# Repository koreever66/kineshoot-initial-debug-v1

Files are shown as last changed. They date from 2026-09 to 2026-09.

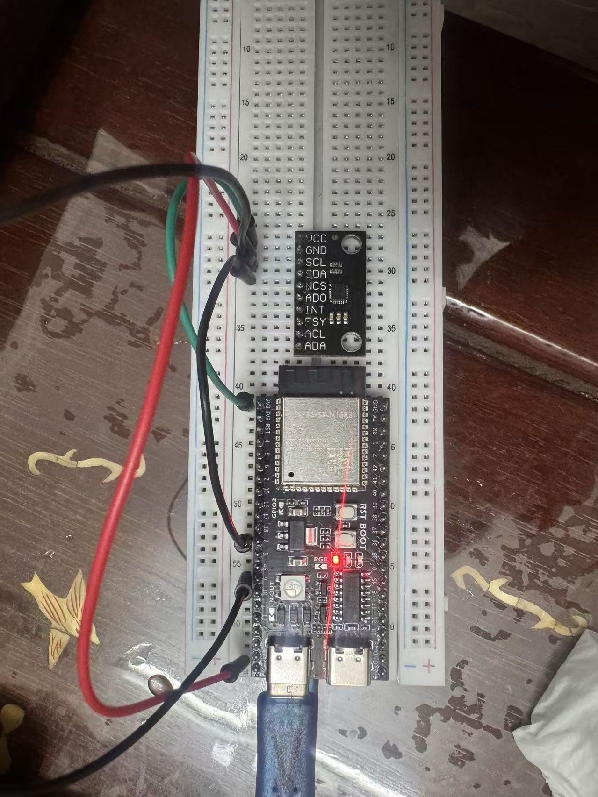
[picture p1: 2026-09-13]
photos/breadboard_rotated.jpg

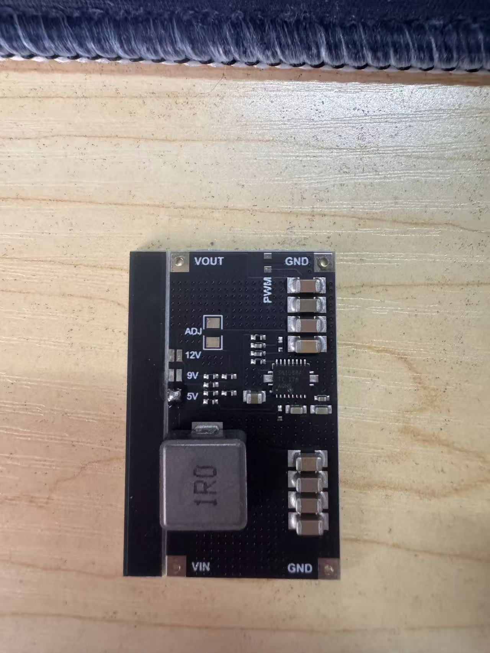
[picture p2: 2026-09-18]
photos/H2/2026-09-18_tps61088_front.jpg

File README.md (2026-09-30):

# 投篮发力链项目：初版硬件调试

本仓库只保存 ESP32-S3 与 ICM-20948 的硬件到货、焊接、接线、固件和第一轮数据采集内容。

不包含此前的项目计划书、商业计划、比赛报名资料和商品采购截图。

## 当前软件入口

- 软件仓库：`https://github.com/koreever66/kineshoot-initial-debug-v2`
- 软件分支：`codex/software-data`
- 软件提交：`ef92a97`（BLE 控制、iOS App、1080p60 与灯光预卷版本）
- 当前基线：`KB-2026-09-15-H1-F4-I1`

本硬件仓库中的 `legacy/` 只保留旧 v1 固件、工具和数据，不用于当前采集。

## 当前基线

```text
software_baseline_id = KB-2026-09-15-H1-F4-I1
software_repository  = koreever66/kineshoot-initial-debug-v2
software_branch      = codex/software-data
software_commit      = ef92a97
interface_revision   = I1
hardware_revision    = H2
```

当前硬件接口：

```text
VCC  -> 3V3
GND  -> GND
ICM SDI/SDA  -> GPIO8
ICM SCLK/SCL -> GPIO9
NCS  -> 3V3
AD0  -> GND
I2C address = 0x68
I2C clock   = 50kHz
WHO_AM_I    = 0xEA
```

详细说明见：

- `docs/hardware/SOFTWARE_BASELINE.md`
- `docs/hardware/H2_HANDOFF.md`
- `docs/hardware/H2_ASSEMBLY_RUNBOOK.md`
- `docs/hardware/SOFTWARE_SYNC_2026-09-19.md`
- `docs/hardware/BATTERY_BOOST_VALIDATION_2026-09-19.md`
- `docs/hardware/FIXATION_RUNBOOK_2026-09-20.md`
- `docs/hardware/WEARABLE_DIRECTION_CALIBRATION_2026-09-21.md`
- `docs/hardware/FIELD_CAPTURE_VALIDATION_2026-09-21.md`
- `docs/hardware/ESP32_REPLACEMENT_BLE_APP_2026-10-01.md`
- `docs/hardware/DUAL_NODE_PLAN_2026-09-20.md`
- `docs/hardware/MEASUREMENT_SHEET_NODE2_2026-09-20.md`
- `docs/hardware/design/node2_preassembly_v1.png`
- `cad/node2_case/README.md`
- `docs/hardware/design/node2_open_top_v1/`
- `docs/hardware/H2_BOM.csv`
- `docs/hardware/WEARABLE_DIMENSIONS.md`
- `docs/hardware/ORDER_RECEIPTS_2026-09-15.md`
- `docs/hardware/DAILY_DEBUG_SUMMARY_2026-09-16.md`
- `reference/software-baseline/`

## 当前硬件

- ESP32-S3-DevKitC-1，N16R8
- ICM-20948 九轴传感器模块
- 面包板和杜邦线
- USB 数据线
- 602535 500mAh 受保护锂电池 ×2
- TP4057-500mA 充电板 ×2
- TPS61088 固定 5V 升压模块 ×1
- SS-12E07G4 3A 开关和 SS12D07VG4 备用开关
- PH2.0 2P/4P 连接器、26AWG 红黑柔性线、热缩管
- 传感器盒、前臂软袋、EVA 泡棉、腕带和前臂绑带
- 电脑：Windows，Arduino IDE 2.3.10

## 目录

```text
legacy/firmware-v1/imu_plotter/     早期串口实时曲线固件
legacy/firmware-v1/imu_csv_logger/  早期 CSV 数据采集固件
legacy/tools-v1/                    早期串口采集和 CSV 绘图脚本
legacy/data-v1/                     早期原始 CSV 数据
legacy/plots-v1/                    早期 CSV 生成的曲线图
photos/                     焊接和面包板接线照片
DEBUG_NOTES.md              问题、解决思路和结果记录
docs/hardware/              H2 固定接口、BOM、装配和测试方案
reference/software-baseline/ 软件固定提交的只读参考文件
```

## 当前状态

- 面包板阶段已经完成 ESP32-S3 与 ICM-20948 通信验证。
- 腕部原 ESP32-S3 在采集第 6 组时出现过热和 BOOT 区域损坏，现已替换为原 Node 2 备用的 ESP32-S3 DevKitC-1 N16R8；接线保持不变。
- 历史阶段出现过 `0x68`、`0x69`、`0x0C` 和 `100kHz`，这些不再作为当前实现目标。
- 当前接口固定为 `0x68`、`50kHz`、`WHO_AM_I=0xEA`。
- 当前软件基线为 F4，使用 10 秒 RAM 记录、LittleFS 批量写入、BOOT 备用触发和 BLE 控制触发。
- 已加入 iPhone 配套 App：`KineShootRemote 1.5.1 (8)`，支持 1080p60、前置/后置切换、缩放、1 秒蓝灯预卷和 14 秒录像。
- 绿灯表示 CSV 与 telemetry 写入完成，不等于球员动作结束；已验证绿灯和 telemetry 可用于对齐视频与 IMU。
- H2 物料已于 2026-09-18 到齐；首版主电源路径为 `电池 -> TP4057 -> SS-12E07G4 3A 开关 -> TPS61088 固定 5V -> ESP32 5V`，不使用 P-MOS。
- H2 已进入实体装配和电气验证阶段；照片、万用表和静止/动态测试尚未完成。

## 下一步

1. 按 `docs/hardware/H2_ASSEMBLY_RUNBOOK.md` 先做电池、TP4057 的断电通断检查和独立充电测试。
2. 按 `docs/hardware/H2_HANDOFF.md` 焊接 PH2.0 和柔性线束；固定 NCS=3V3、AD0=GND。
3. 先只用 USB 验证 `0x68` 和 `WHO_AM_I=0xEA`，再接入升压电源链。
4. 完成腕部固定、前臂固定和应力释放。
5. 完成 10 秒静止测试和小幅动态测试。
6. 对替换后的 ESP32 做电池供电 BLE 连续采集，检查温升、复位、丢样和结构固定。
7. 提交 H2 照片、测试结果和已知风险。

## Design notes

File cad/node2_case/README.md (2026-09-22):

# Node 2 Upper-Arm Open Case

Parametric JSCAD model for the second-node upper-arm enclosure.

```text
revision: N2-CASE-OPEN-V1.2
body outer size: 125 x 75 x 32 mm
internal nominal: 120 x 70 x 23.5 mm
top: open perimeter fence, no lid
arm circumference input: 300 mm relaxed / 317 mm flexed
bottom cradle sagitta: 6 mm
strap interface: two external stations, direct 50 mm strap
```

## Commands

```bash
npm install
npm run build
npm run render
npm run serve
```

- `build`: exports STL, 3MF, and the layout manifest into `out/`.
- `render`: uses local Chrome or Edge through Playwright Core to create isometric, top, and side PNG previews.
- `serve`: starts the interactive Three.js viewer.

The shell model excludes electronic modules. Module blocks in the viewer and manifest are mechanical placeholders only.

Measured inputs currently applied:

```text
lateral upper-arm width: 100 mm
ESP32 envelope: 63.6 x 27.94 x 12 mm
TPS61088 maximum height: 11 mm
battery safe envelope: 43 x 30 x 15 mm
dual Type-C opening: one 32 x 7 mm rectangular slot
strap natural / comfortable length: 500 mm / 680-700 mm
```

The ICM maximum bent height measured by the user is 32 mm. The current model assumes the ICM is laid sideways and its 4P cable is routed flat. Verify the installed height after that routing before the final print; if it exceeds 23.5 mm above the deck, raise the fence parameter.

Revision V1.2 shortens the ICM partition to the distal/front pocket so it no
longer crosses the TPS61088 footprint. The build also checks every module
against the partition, not only against the outer walls.

## Generated Files

```text
out/node2_open_top_v1.stl
out/node2_open_top_v1.3mf
out/node2_open_top_v1_manifest.json
out/node2_open_top_v1_preview_iso.png
out/node2_open_top_v1_preview_top.png
out/node2_open_top_v1_preview_side.png
```

The current model keeps the fixed electrical interface unchanged:

```text
ICM VCC       <- ESP32 3V3
ICM GND       <- ESP32 GND
ICM SDI/SDA   <- GPIO8
ICM SCLK/SCL  <- GPIO9
ICM NCS       -> 3V3
ICM AD0       -> GND
address       = 0x68
clock         = 50kHz
WHO_AM_I      = 0xEA
```

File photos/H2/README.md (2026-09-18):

# H2 Photo Manifest

Put H2 assembly and verification photos in this directory.

Arrival and pre-check evidence captured on 2026-09-18:

- `2026-09-18_tps61088_front.jpg`: actual TPS61088 front side with VIN/VOUT/GND, 5V/9V/12V/ADJ pads and PWM pad.
- `2026-09-18_tps61088_back.jpg`: actual TPS61088 back side and dimensions marking.
- `2026-09-18_tp4057_500ma.jpg`: actual TP4057-500mA board and four BAT through-holes.

Required photos:

1. ESP32 and ICM wiring overview.
2. Both ends of the PH2.0 4P connector.
3. Close-up of ICM NCS tied to 3V3 and AD0 tied to GND.
4. Battery-to-TP4057 solder joints.
5. Switch and boost module placement.
6. Wrist-mounted sensor unit, front and back.
7. Forearm battery and main unit pouch.
8. Full wearable placement.
9. Strain relief close-up.
10. Multimeter continuity or voltage checks.

Do not upload screenshots containing personal information, order pages, names, phone numbers, or addresses.

These arrival photos are not verification evidence for soldering, charging, boost output, mechanical fit, or motion testing.

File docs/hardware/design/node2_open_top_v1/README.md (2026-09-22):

# Node 2 Open-Top Preview v1

Previews generated from `cad/node2_case`.

```text
preview_iso.png  isometric view
preview_top.png  top view with module placeholders
preview_side.png side view showing the open fence and shallow cradle
```

Printable model files:

```text
cad/node2_case/out/node2_open_top_v1.stl
cad/node2_case/out/node2_open_top_v1.3mf
```

Design summary:

```text
body outer size: 125 x 75 x 32 mm
internal nominal: 120 x 70 x 23.5 mm
top: open
strap stations: two, direct 50 mm strap hooks
arm circumference: 300 mm relaxed / 317 mm flexed
ICM partition: distal/front pocket only; checked against module footprints
```

This is a prototype mechanical enclosure. It does not modify the ICM, ESP32, power path, firmware, or software protocol.

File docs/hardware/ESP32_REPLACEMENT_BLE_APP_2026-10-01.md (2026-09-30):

# ESP32 Replacement, BLE Trigger, and Mobile App - 2026-10-01

## Replacement Event

The previous wrist-node ESP32-S3 failed while triggering capture 6. The operator reported a burning smell. The original red power LED and GPIO48 RGB LED no longer illuminated, and visible damage was found around the BOOT-key area. Power was removed immediately and the board was retired.

The spare ESP32-S3 DevKitC-1 N16R8 originally reserved for Node 2 was installed in the wrist-node position.

The electrical interface did not change:

```text
ICM VCC       -> ESP32 3V3
ICM GND       -> ESP32 GND
ICM SDI/SDA   -> GPIO8
ICM SCLK/SCL  -> GPIO9
ICM NCS       -> 3V3
ICM AD0       -> GND
BOOT trigger  -> GPIO0 to GND
RGB status    -> GPIO48
I2C address   -> 0x68
I2C clock     -> 50 kHz
WHO_AM_I      -> 0xEA
```

Initial bring-up was performed with USB only. The battery, TP4057, power switch, and TPS61088 were disconnected during flashing and first validation.

## BLE and App Integration

Firmware now advertises only the custom BLE control service:

```text
Name: KineShoot-Cam
Service UUID: 6b1d0001-9a3f-4d2a-8f6f-6b1d00000001
Characteristic UUID: 6b1d0002-9a3f-4d2a-8f6f-6b1d00000002
Command 0x01: start capture
```

The iPhone app starts video recording, waits one second to record the blue-light pre-roll, then writes `0x01` to the ESP32. The ESP32 performs the same capture routine used by the BOOT fallback.

Expected serial handshake:

```text
BLE_CONTROL_READY,name=KineShoot-Cam,...
BLE_CONNECTED
BLE_COMMAND,capture
CAPTURE_START,file=/capture_001.csv,seconds=10
CAPTURE_DONE,...
```

The current app build is `KineShootRemote 1.5.1 (8)`, with 1080p60, front/rear switching, zoom, a 1-second blue pre-roll, and a 14-second recording window.

## Verification on the Replaced Board

The replacement board completed:

- USB flashing and serial initialization
- ICM-20948 initialization at `0x68`
- repeated 10-second captures
- LittleFS CSV and telemetry writes
- BOOT-triggered capture
- BLE-triggered capture from the iPhone app
- RGB state changes visible in 60 fps video

One verified alignment session is:

```text
session_20261001_034814/capture_001.csv
2268 rows, 9.9904 s, 226.92 Hz
```

The corresponding 15.61-second 1080p60 video shows the green write-complete LED at approximately `12.526 s`. Telemetry reports `11.535 s` from capture start to write completion, giving an estimated IMU start at approximately `0.991 s` in the video, consistent with the configured 1-second blue pre-roll.

## Metadata Provenance Correction

The software side corrected exported metadata after this hardware review. Software commit `6f6e7fc` now records the replacement-board baseline as `H2`, adds a dedicated BLE/App export wrapper using `trigger_source = ble_command`, and preserves `boot_button` only for physical BOOT-triggered exports. The known `032715/capture_011-013` and `034814/capture_001` metadata were corrected without changing any CSV IMU values.

## Hardware Notes and Next Checks

- Green indicates that the CSV and telemetry write completed; it is not the physical end of the player's motion.
- Keep the camera aimed and focused on the device before pressing Start so the blue-to-red transition is recorded.
- Do not connect USB and the battery-boost output at the same time.
- Inspect the replacement board area after repeated captures for heating, connector strain, or intermittent resets.
- Secure the replacement board and strain-relieve the I2C/power wiring inside the enclosure.
- Run a battery-powered BLE capture series and compare sample continuity, reset count, and RGB behavior to the USB-powered baseline.
- Record the next enclosure revision or fastening change if the replacement board dimensions alter the current wrist-node fit.

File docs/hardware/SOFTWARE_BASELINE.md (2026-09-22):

# Software Baseline Reference

This file records the software baseline consumed by the hardware repository. The software repository remains the source of truth.

```text
software_baseline_id = KB-2026-09-15-H1-F4-I1
software_repository  = koreever66/kineshoot-initial-debug-v2
software_branch      = codex/software-data
software_commit      = ab44f2a
interface_revision   = I1
hardware_revision    = H2
```

## Read-Only Copies

The following files were copied from the fixed software commit into `reference/software-baseline/`:

| File | Source path | Git blob SHA |
|---|---|---|
| `CANONICAL_BASELINE.md` | `docs/CANONICAL_BASELINE.md` | `717afcd5a1f7dec0601232ad5305f42f7df4c3bd` |
| `INTERFACE.md` | `docs/INTERFACE.md` | `23475d58d4e2ef8b0a49b8c9174069124ae8cff5` |
| `project.json` | `project.json` | `4e9d042032dbe7b47f5d5ae87cf21e37db2b0cb8` |

These copies are read-only references. Hardware changes must not modify them.

## Fixed Interface

```text
ESP32-S3 GPIO8  <-> ICM-20948 SDI / SDA
ESP32-S3 GPIO9  <-> ICM-20948 SCLK / SCL
ESP32-S3 3V3    <-> ICM-20948 VCC
ESP32-S3 GND    <-> ICM-20948 GND
ESP32-S3 3V3    <-> ICM-20948 NCS
ESP32-S3 GND    <-> ICM-20948 AD0

I2C address: 0x68
I2C clock:   50 kHz
WHO_AM_I:    0xEA
```

## Prohibited

- Do not use `0x69` or `0x0C` as the long-term primary address.
- Do not leave `AD0` or `NCS` floating.
- Do not switch or bypass the 3.3V power path.
- Do not modify firmware, tools, data formats, record duration, triggers, or software protocol.
- Do not modify the software repository.

## F4 Runtime Contract

```text
firmware directory: firmware/imu_flash_logger_v4/
record duration:    15 seconds
buffering:          RAM during capture, batched LittleFS write after capture
sample rate:        nominal about 220-225 Hz
observed F4:        approximately 226.9 Hz in current exports
hardware acceptance 210-240 Hz or median interval 4.0-4.8 ms
maximum interval:   <=10 ms
accelerometer:      +/-16g
gyroscope:          +/-2000dps
trigger:            short press BOOT
USB CDC On Boot:    Enabled
status LED:         WS2812B RGB on GPIO48
LED colors:         blue=idle/running, red=capture, green=LittleFS write complete
power switch check: after changing source, proceed only when blue is on; if not, press RST once
export layout:      timestamped session directories
CSV fields:         timestamp_us, ax_mg, ay_mg, az_mg,
                    gx_dps, gy_dps, gz_dps, temp_c
metadata fields:    power_source, trigger_source, motion_speed
zero-sample guard:  reject 0-row capture files since software commit 9beb75a
field captures:     approximately 3403-3404 rows in the 2026-09-21 session
```

## Current Software Test Power Boundary

当前软件对话的测试供电仍然属于 H1：

```text
电脑 USB -> ESP32
或
充电宝 5V -> ESP32
```

因此当前软件测试不经过：

```text
电池
TP4057
3A 开关
TPS61088
```

软件接口只依赖：

- ESP32 5V 输入保持稳定。
- BOOT/GPIO0 和 RST 行为。
- GPIO48 RGB 状态反馈。
- USB CDC On Boot、采样、记录和导出协议。

H2 首版采用的直接 3A 开关属于硬件电源实现，不改变软件接口。P-MOS 只保留为实测不合格时的硬件回退方案。现阶段软件端使用电脑 USB 或充电宝测试时，不需要等待 H2 电源链完成。

进入 H2 整机测试后必须遵守：

- 电脑 USB 和电池输出不能同时连接。
- TP4057 充电时关闭负载。
- USB 烧录或导出时断开电池输出。
- ESP32 5V 输入必须来自单一电源，避免双 5V 倒灌。

Hardware owns only the physical implementation, power, connectors, mounting, and verification.

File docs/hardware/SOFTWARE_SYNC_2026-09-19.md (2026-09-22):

# Software-to-Hardware Sync 2026-09-19

软件端报告：`KineShoot_硬件联调测试报告_2026-09-19.docx`

固定基线：

```text
hardware_revision = H2
software_revision = F4
interface_revision = I1
software_commit = ab44f2a
ICM-20948 I2C = 0x68
I2C clock = 50kHz
WHO_AM_I = 0xEA
```

## 1. 已知通过项

- USB 供电下，START 和 BOOT 两次静止采集均通过。
- 两次 USB 数据均约 2269 到 2270 行，采样率约 226.9Hz，最大间隔小于 6.32ms。
- I2C 固定地址诊断持续返回 `tx=0, rx=1, who=0xEA`。
- 重新上传 F4 后，充电宝模式两次桌面静止采集恢复有效，均约 2270 行。
- 恢复后的两次数据无采样缺口、无饱和，重力模长约 997 到 999mg。
- 软件端 action-chain 会话已包含 6 次有效采集，并已加入 0 行空采集文件拒绝逻辑。
- 电池供电链路完成 5 次冷启动；随后 3 次静止和 2 次小幅举臂采集已由软件端验收通过。

## 2. 当前开放问题

### P0：切换供电后出现空表头采集

第一次从 USB 切到充电宝后，连续三次采集都只有 64 字节 CSV 表头，数据行为 0。重新检查连接并重刷 F4 后恢复，因此当前证据指向连接稳定性或供电切换过程，而不是采样算法。

当前状态：重新检查连接并重刷 F4 后已恢复；电池供电下 3 次静止加 2 次小幅举臂采集已通过软件端验收。

### P0：四线连接器、NCS、AD0 的机械稳定性

需要确认轻拨线束时：

- SDA/SCL 不中断。
- 地址始终保持 `0x68`；不出现 `0x0C`。
- `NCS` 与 `VCC` 保持导通。
- `AD0` 与 `GND` 保持导通。

### P1：ICM 端供电稳定

需要实测：

- ICM `VCC` 对 `GND` 约 3.3V。
- 充电宝接入、线束轻拨和静止记录期间没有明显跌落。
- `GND` 共地稳定。

### P1：从充电宝切回 USB 的冷启动时序

软件端观察到从充电宝切回 USB 后，连续三次按 RST 蓝灯未亮，第四次恢复。需要统计五次冷启动，区分 USB 枚举延迟、复位时序和 IMU 初始化重试。

当前状态：电池供电路径已完成 5 次冷启动，5/5 蓝灯恢复，无额外 RST、无反复复位、无保护板跳闸；USB 枚举延迟的历史现象继续保留为观察项。

## 3. 硬件端复测顺序

### 测试 A：I2C 静态稳定性

1. 只用电脑 USB 给 ESP32 供电。
2. 运行 I2C 扫描。
3. 轻拨四根 PH2.0 线束。
4. 轻拨 ICM 端 `NCS` 和 `AD0` 跳线。
5. 观察 2 到 3 分钟。

通过标准：

- [ ] 地址保持 `0x68`。
- [ ] `WHO_AM_I=0xEA` 稳定。
- [ ] 不出现 `0x0C`。
- [ ] 无通信中断。

### 测试 B：端点和供电测量

断电通断检查：

- [ ] `NCS` 对 `VCC` 导通。
- [ ] `AD0` 对 `GND` 导通。
- [ ] `VCC` 对 `GND` 不导通。
- [ ] SDA 对 GND 不导通。
- [ ] SCL 对 GND 不导通。

上电电压检查：

- [ ] ICM `VCC` 约 3.3V。
- [ ] ICM `GND` 与 ESP32 `GND` 共地。
- [ ] 轻拨线束后电压仍稳定。

### 测试 C：USB 静止采集

- [ ] 10 秒静止 BOOT 采集约 2269 行。
- [ ] `write_failed=0`。
- [ ] 无 ERR、无 reset。
- [ ] 最大间隔小于 10ms。

### 测试 D：充电宝静止采集

- [ ] 切换前先关闭或断开负载。
- [ ] 充电宝 5V 接入后等待 10 秒。
- [ ] 只做一次站立静止 10 秒采集。
- [ ] 约 2269 行，不能是 64 字节空表头。
- [ ] 轻拨线束时数据不中断。

### 测试 E：五次冷启动记录

每次按以下顺序执行：

```text
1. 拔掉 USB。
2. 等待 10 秒。
3. 重新插入 USB。
4. 等待 5 秒。
5. 只按一次 RST。
6. 最多等待 10 秒。
```

每次记录：

```text
第几次：
USB 插入后 COM5 出现时间：
按 RST 前灯色：
按 RST 后灯色：
串口首行：
IMU_INIT 状态：
是否一次恢复：
失败时是否有红灯：
失败时是否有 COM5：
```

通过标准：

- [ ] 连续五次冷启动都恢复。
- [ ] 或者明确记录失败模式，并证明失败原因不是接触不良。

## 4. 动态测试门槛

满足以下条件后，才继续举臂、蹲起和投篮动态测试：

- [x] 充电宝模式和电池模式下均完成有效静态采集并通过软件端验收。
- [ ] 最大间隔小于 10ms，20ms 以上缺口为 0。
- [ ] `write_failed`、饱和和复位均为 0。
- [x] 五次电池冷启动达到五次成功。
- [ ] 轻拉线束和切换供电时 ICM 数据通路不失效。

## 5. 责任边界

软件端负责：

- F4 固件零样本保护，当前已在软件提交 `9beb75a` 后实现。
- CSV 和元数据校验。
- 串口日志与采样算法分析。

硬件端负责：

- 四线连接器接触稳定性。
- NCS/AD0 固定电平的机械与电气可靠性。
- ICM 3V3/GND 供电稳定。
- 充电宝到 USB 的切换时序和冷启动记录。
- 线束应力释放和插头锁扣状态。

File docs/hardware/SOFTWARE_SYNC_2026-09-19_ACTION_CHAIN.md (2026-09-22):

# Software Sync - 2026-09-19 Action-Chain Validation

Software branch: `codex/software-data`

Software commit at action-chain validation: `1ec5968`

Latest validated software commit: `ab44f2a`

Last pushed software remote head at review time: `276b312`

## Purpose

Synchronize the hardware repository with the latest software-side validation
results before strap fixation and component embedding.

## Latest Validated Setup

```text
ESP32-S3
ICM-20948 at 0x68 / WHO_AM_I 0xEA
ICM VCC <- ESP32 3V3
ICM GND <- ESP32 GND
ICM SDI/SDA <- GPIO8
ICM SCLK/SCL <- GPIO9
ICM NCS -> 3V3
ICM AD0 -> GND
5 V power bank
BOOT-button capture trigger
```

The latest action-chain session contains six valid captures:

```text
static x2
slow arm raise x1
one simulated shot x1
two simulated shots x1
two squats x1
```

Each file has approximately 2269 rows, approximately 226.9 Hz sample rate, no
gaps of 20 ms or more, and no acceleration or gyroscope saturation.

## Hardware-Side Mechanical Requirements

- Preserve the current soldered four-wire connection.
- Add strain relief before the cable enters the ESP32 or ICM.
- Keep the sensor module mechanically isolated from the power bank.
- Secure the power bank so its cable cannot pull the ESP32 connector.
- Keep USB-C, BOOT, and RGB LED accessible.
- Do not coat solder joints directly with hot glue.
- Mark sensor orientation on the strap or enclosure.
- After assembly, repeat NCS-to-3V3, AD0-to-GND, and VCC-to-GND checks.

## Acceptance After Fixation

Before court shooting, repeat:

```text
3 static captures
2 arm-raise captures
```

All five captures must pass sample count, gap, saturation, and file-size checks.
If any capture fails, inspect the cable path before proceeding to dynamic
shooting.

## Battery and Boost Integration Sequence

The current power bank remains the validated capture baseline. Do not replace
it with the battery until the following sequence passes.

Target main path:

```text
3.7 V protected battery
-> TP4057 charge module BAT+ / BAT-
-> SS-12E07G4 3 A main switch on battery positive
-> TPS61088 fixed 5 V boost input
-> TPS61088 5 V output to ESP32 5V and GND
```

`SS12D07VG4` must not carry the main boost input current. It is only allowed in
the low-current P-MOSFET fallback control path.

Validation order:

1. Measure battery polarity and open-circuit voltage before connection.
   Expected approximately 3.0-4.2 V.
2. Connect only the battery to TP4057. Do not connect ESP32 or TPS61088 yet.
3. Charge through TP4057 and verify charging current is approximately 500 mA
   and final battery voltage is approximately 4.2 V.
4. Verify the TP4057 BAT+ / BAT- output polarity and voltage.
5. Add the SS-12E07G4 switch in the battery-positive main path.
6. Connect the switched battery output to TPS61088 input.
7. Verify TPS61088 no-load output is 5.00 V before connecting ESP32.
8. Apply a short 0.5-1 A load test. Output should remain at or above about
   4.85 V and the switch temperature should remain acceptable.
9. Connect TPS61088 5 V output only to ESP32 5V and GND. Never connect boost
   output to ESP32 3V3 or ICM VCC.
10. Confirm ESP32 boot has no brownout and ICM VCC remains approximately 3.3 V.
11. Run three static captures and two arm-raise captures on battery power.
12. Keep the power bank available as fallback until all five captures pass.

TP4057 does not provide load sharing. The ESP32 load must be switched off while
charging. Never connect USB 5 V and battery-boost 5 V to the ESP32 at the same
time.

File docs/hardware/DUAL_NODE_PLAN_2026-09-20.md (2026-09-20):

# Dual-Node Hardware Plan - 2026-09-20

Status: hardware proposal for the second node. Software protocol and time-sync method remain owned by the software conversation.

## 1. Target Architecture

Keep the two nodes electrically independent:

```text
Node 1: forearm
  battery B1 -> TP4057 -> switch -> TPS61088 5V -> ESP32 #1
  ICM #1 -> 4P cable -> ESP32 #1

Node 2: upper arm
  battery B2 -> TP4057 -> switch -> TPS61088 5V -> ESP32 #2
  ICM #2 -> 4P cable -> ESP32 #2
```

Do not connect the two nodes through a shared battery or shared 5V rail for the first revision.

2026-09-20 decision: Node 2 will use the second protected battery B2. The two nodes will not share a battery, 5V rail, or ground in the first revision. No inter-node signal wire will be installed until the software conversation defines the synchronization method.

## 2. Additional Hardware Required

Required:

- one ESP32-S3-N16R8 board
- one ICM-20948 module
- one TP4057-500mA charging module
- one fixed-5V TPS61088 boost module
- one 26AWG red and black silicone wire set
- one USB-C data cable for programming the second board
- two 5cm upper-arm elastic straps or equivalent reusable arm bands

Already available or reusable:

- battery B2, because two protected 602535 500mAh batteries were purchased
- spare SS-12E07G4 3A switch from the multi-pack
- PH2.0 4P connectors for the second ICM harness
- PH2.0 2P connectors for battery B2
- heat shrink, EVA foam, Velcro, labels, and spare flexible wire

Do not add a second battery-protection board in series unless the battery does not already contain one. The purchased 602535 cells already include protection boards.

## 3. Upper-Arm Placement

Proposed location:

```text
lateral upper arm
center approximately 10cm proximal to the elbow
long axis parallel to the humerus
```

Mechanical requirements:

- keep the case away from the elbow crease and shoulder
- use the distal end of the case for the ICM sensor
- use the proximal/upper end for the battery to move mass toward the shoulder
- keep the battery from pressing on the ICM compartment
- use EVA or a TPU liner on the skin-facing surface
- use two arm bands to prevent rotation and sliding
- mark node ID `N2` and an orientation arrow on the case

Keep the same fixed interface:

```text
ICM VCC       <- ESP32 3V3
ICM GND       <- ESP32 GND
ICM SDI/SDA   <- GPIO8
ICM SCLK/SCL  <- GPIO9
ICM NCS       -> 3V3
ICM AD0       -> GND
I2C address   = 0x68
I2C clock     = 50kHz
WHO_AM_I      = 0xEA
```

## 4. 3D-Printed Enclosure

Use a two-piece clamshell or removable-lid shell.

Recommended material:

```text
PETG, ASA, PA12, or another durable non-conductive material
```

Recommended structure:

- curved skin-facing surface matching the upper-arm radius
- 2.5 to 3mm wall thickness
- M2.5 heat-set inserts instead of screwing directly into printed plastic
- separate internal sensor compartment at the distal/elbow end
- main electronics compartment for ESP32, TPS61088, TP4057, and switch
- battery pocket separated from the boost module by foam
- cable channels with integrated strain-relief posts
- removable or transparent RGB window
- BOOT and RST access holes or a removable service window
- USB-C access aligned with the ESP32 COM port
- switch access without opening the lid

Do not place the battery or metal parts directly over the ESP32 antenna area. Keep the antenna at a plastic-only edge of the enclosure.

## 5. Sensor Isolation Inside the Shell

For the upper-arm node, place the ICM in a small internal pocket rather than directly bolting it to the main electronics plate.

- add 1 to 2mm EVA or TPU between ICM and shell
- anchor the 4P cable to the pocket before it reaches ICM solder joints
- leave a 1 to 2cm service loop
- keep battery and boost wiring away from the ICM cable
- use only small removable glue dots at the PCB edges after validation; do not fully pot the ICM

## 6. Validation Order

1. Verify Node 2 through USB only:

```text
0x68
WHO_AM_I = 0xEA
50kHz
```

2. Verify the Node 2 battery path:

```text
battery -> TP4057 -> switch -> TPS61088
TPS61088 VOUT approximately 5.0V
ESP32 5V at or above approximately 4.85V
ICM VCC approximately 3.3V
```

3. Verify five cold starts.
4. Run three static captures and two small arm-raise captures.
5. Only after the upper-arm node passes, integrate it with Node 1 for multi-node capture.

## 7. Software Boundary

Hardware owns only the second node power path, connectors, enclosure, mounting, and electrical tests. The software conversation must decide:

- simultaneous capture procedure
- node identity metadata
- timestamp synchronization method
- wireless or wired synchronization wiring if required
- event alignment and joint-angle computation

No firmware or data-format change is made by this hardware plan.

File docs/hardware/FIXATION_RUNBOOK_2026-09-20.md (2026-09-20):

# H2 Wearable Fixation Runbook - 2026-09-20

Baseline:

```text
hardware_revision = H2
software_validated_commit = 3db2b5d
interface_revision = I1
ICM address = 0x68
I2C clock = 50kHz
WHO_AM_I = 0xEA
```

This stage changes only mechanical fixation, cable routing, and strain relief. Do not change firmware, tools, data format, connector pinout, `NCS`, or `AD0`.

## 0. Dry-Fit Enclosure Decision

On 2026-09-20, the dry-fit enclosure changed from the soft pouch to the already purchased transparent plastic storage box:

```text
approx. 10 x 7 x 2.3cm
```

The box is currently the mechanical dry-fit enclosure. It is not yet the final production enclosure.

Rules for this box:

- Keep all modules on one layer; do not stack ESP32, boost module, and battery into a three-layer sandwich.
- Place ESP32 with the BOOT, RST, and RGB side facing the transparent lid.
- Mark and drill a small BOOT access hole only after the final dry fit.
- The transparent lid is the RGB visibility window; no second LED and no firmware change.
- If the box presses the forearm or slides, add EVA to the skin side and use the 5cm strap plus a second anti-slip strap or Velcro base.
- Keep the box away from the wrist crease and elbow crease.
- Charge TP4057 with the box open or with a deliberate charging-access opening; do not charge in a closed, unattended box.
- Use grommets, silicone tubes, or heat-shrink sleeves in every cable exit hole.
- Keep the 4P connector latch serviceable; do not glue the connector into the box.

## 1. Pre-Fixation Gate

- [ ] Battery switch OFF.
- [ ] Computer USB disconnected.
- [ ] Charging power bank disconnected.
- [ ] The verified battery/boost chain is not modified.
- [ ] Take before-fixation photos of the wrist unit, forearm unit, and cable path.

Keep the fixed interface unchanged:

```text
ICM VCC       <- ESP32 3V3
ICM GND       <- ESP32 GND
ICM SDI/SDA   <- GPIO8
ICM SCLK/SCL  <- GPIO9
ICM NCS       -> 3V3
ICM AD0       -> GND
```

## 2. Wrist Sensor Unit

- [ ] Put 2mm EVA on the skin-facing side of the ICM box.
- [ ] Keep the ICM box near the wrist at 2 to 4cm from the wrist crease toward the elbow.
- [ ] Mark one arrow on the box toward the elbow and keep that orientation every time.
- [ ] Route the cable out of the elbow-side or forearm-side of the box, not the palm/ball side.
- [ ] Add a 1 to 2cm service loop inside or immediately outside the box.
- [ ] Anchor the cable to the box before it reaches the soldered ICM pins.
- [ ] Use the 3.8cm strap with the verified nonstandard wrap method.
- [ ] Confirm the box does not press the wrist crease or collide with the palm during wrist flexion.

Pass criteria:

- [ ] No movement after a gentle 5-second tug on the cable.
- [ ] Connector latch remains fully engaged.
- [ ] Wrist flexion and extension do not make the box hit the hand.
- [ ] Cable does not rub the skin or form a sharp bend at the box exit.

## 3. Forearm Battery and Main-Control Unit

Recommended single-layer layout inside the 10 x 8cm pouch:

```text
Near wrist: TPS61088, SS-12E07G4 switch, TP4057
Middle:     ESP32-S3
Near elbow: 500mAh battery
```

- [ ] Keep modules in one layer where possible.
- [ ] Put EVA or thin foam between the battery, PCB modules, and pouch wall.
- [ ] Keep the battery close to the elbow to reduce weight near the wrist.
- [ ] Keep all exposed solder joints covered by heat shrink or Kapton tape.
- [ ] Keep the switch accessible without opening the whole pouch.
- [ ] Keep USB-C and BOOT/RGB accessible for maintenance.
- [ ] Anchor the battery wires so battery weight does not pull on TP4057 pads.
- [ ] Anchor the boost input/output wires so the switch and connectors do not carry tension.

Pass criteria:

- [ ] Pouch does not slide down the forearm during a gentle arm raise.
- [ ] No module presses into the elbow crease.
- [ ] USB-C port is not loaded by the cable when connected.
- [ ] No battery protection-board corner presses directly on a PCB.

## 4. Cable Strain Relief

- [ ] Leave a 1 to 2cm service loop at each end of the 4P cable.
- [ ] Anchor the 4P cable near the ICM box.
- [ ] Anchor the 4P cable near the ESP32.
- [ ] Do not let the soldered ICM pins take the cable tension.
- [ ] Do not let the PH2.0 connector be the mechanical stop.
- [ ] Keep the cable away from the switch handle, battery edge, and sharp PCB corners.
- [ ] Do not cover the PH2.0 latch; it must still unplug for service.
- [ ] Use tape, Velcro, or small zip ties, but do not overtighten and crush the wires.

## 5. Post-Fixation Electrical Checks

Power OFF first:

- [ ] `NCS` to `VCC` still conducts.
- [ ] `AD0` to `GND` still conducts.
- [ ] `VCC` to `GND` does not conduct.
- [ ] The four 4P lines remain in the fixed order.
- [ ] Battery polarity has not changed.

Power ON with battery:

- [ ] TPS61088 VOUT approximately 5.0V.
- [ ] ESP32 5V at or above approximately 4.85V.
- [ ] ICM VCC approximately 3.3V.
- [ ] RGB blue is stable.
- [ ] No reset during gentle cable movement.

## 6. Post-Fixation Capture Validation

Only after mechanical fixation and electrical checks pass, run:

```text
3 static captures
2 small arm-raise captures
```

Every file must remain:

```text
approximately 2269 rows
sample rate approximately 226.9Hz
maximum interval below 10ms
no gaps of 20ms or more
no empty file
no partial file
no saturation
no reset
write_failed = 0
```

If any capture fails, inspect cable strain relief and connector locking before changing any firmware.

## 7. Shared Handoff Result Format

Write the following to `shared/handoffs/hardware.md` when fixation is complete:

```text
hardware_commit:
fixation_date:
wrist_unit: pass/fail
forearm_unit: pass/fail
strain_relief: pass/fail
NCS_to_VCC:
AD0_to_GND:
ICM_VCC:
ESP32_5V:
TPS61088_VOUT:
static_captures:
arm_raise_captures:
reset_count:
write_failed_count:
remaining_risks:
```

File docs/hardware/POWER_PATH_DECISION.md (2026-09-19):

# H2 Power Path Decision

## Main Scheme

```text
3.7 V protected battery
-> TP4057 BAT+ / BAT-
-> SS-12E07G4 3 A switch on the battery positive path
-> TPS61088 fixed 5 V boost
-> ESP32 5V and GND
```

`SS-12E07G4` is the current main switch. It must be tested for low-voltage DC
contact resistance, voltage drop, and temperature rise under the real load.

## Fallback Scheme

```text
3.7 V protected battery
-> P-MOSFET high-side switch
-> SS12D07VG4 low-current control
-> TPS61088 fixed 5 V boost
-> ESP32 5V and GND
```

The fallback is used only if the `SS-12E07G4` direct-switch path fails
low-voltage load testing.

- `SS12D07VG4` is rated around 0.5 A and must not carry the main boost input
  current.
- A finished P-MOS module must support reliable conduction with a 3.0-4.2 V
  input range.
- If a finished module is not available, use the discrete AO3415 option with a
  100 k gate-source resistor and a 1 k gate control resistor.
- Do not use F5305S 5-36 V modules; their input range does not support the
  required 3.0 V condition.
- Verify EN/CTRL polarity and voltage levels before connecting the boost module.

## Load-Sharing Constraint

TP4057 does not provide load sharing.

```text
Charging -> ESP32 load must be off
USB 5 V -> battery output must be off
Battery boost 5 V -> USB 5 V must not be connected at the same time
```

The ESP32 may receive only one 5 V source at a time.

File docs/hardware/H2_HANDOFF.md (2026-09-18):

# H2 Hardware Handoff

基线：

```text
baseline_id       = KB-2026-09-15-H1-F4-I1
interface_revision = I1
hardware_revision  = H2
hardware_branch    = codex/hardware-bringup
```

当前状态：H2 物料已到齐，进入实体装配和电气验证阶段；尚未完成最终装配、照片、万用表检查和静止/动态测试。本文档中的“通过”必须在真实测量和照片完成后才能勾选。

```text
H2 status = assembling_and_verification
```

H2 不能标记为完成。

## 1. 硬件边界

本仓库只负责：

- 硬件物料和 BOM。
- 接线和连接器。
- 底板、腕部和前臂固定。
- 电源开关和电源路径。
- 线束应力释放。
- 万用表检查和硬件测试。

本仓库不负责：

- 固件。
- 软件协议。
- CSV 和 meta 数据格式。
- 采样率、量程、触发方式。
- 数据分析和模型。

## 2. 固定接口

```text
ICM VCC  -> ESP32 3V3
ICM GND  -> ESP32 GND
ICM SDI/SDA  -> ESP32 GPIO8
ICM SCLK/SCL -> ESP32 GPIO9
ICM NCS  -> ESP32 3V3
ICM AD0  -> ESP32 GND

I2C address = 0x68
I2C clock   = 50kHz
WHO_AM_I    = 0xEA
```

禁止：

- `0x69` 或 `0x0C` 作为长期主地址。
- `NCS` 或 `AD0` 悬空。
- 切换或旁路 3.3V 电源路径。
- 改为软件未批准的连接器线序。

## 3. 连接器和线序

连接器：PH2.0 2.0mm 4P 公母带线。

```text
Pin 1 = VCC = 3V3
Pin 2 = GND = 公共地
Pin 3 = ICM SDI/SDA = GPIO8
Pin 4 = ICM SCLK/SCL = GPIO9
```

ICM 端就近固定：

```text
ICM NCS -> 3V3
ICM AD0 -> GND
```

NCS 和 AD0 固定后不需要 6P 连接器。4P 线长优先 10 到 15cm，最多先不超过 20cm。焊接后用万用表逐根检查，不能只靠线色。

## 3.1 GPIO48 RGB 状态灯

F4 主固件使用 ESP32-S3 板载 GPIO48 WS2812B：

```text
蓝色：固件运行，等待记录
红色：正在执行 10 秒记录
绿色：LittleFS 写盘成功，随后恢复蓝色
```

切换电源后：

- 先确认 BOOT 没有按住。
- 检查 RGB 是否蓝色常亮。
- 只有蓝灯不亮时，按一次 RST。
- 蓝色常亮后才允许开始 BOOT 记录或导出。

不可控红色电源灯只表示开发板有电，不能表示 F4 已运行。该状态灯是板载功能，不需要额外接线。

## 4. 接线图

```text
                         +----------------+
ESP32-S3 3V3 -----------| PH2.0 4P Pin 1 |-------- ICM VCC
ESP32-S3 GND -----------| PH2.0 4P Pin 2 |-------- ICM GND
ESP32-S3 GPIO8 ---------| PH2.0 4P Pin 3 |-------- ICM SDI/SDA
ESP32-S3 GPIO9 ---------| PH2.0 4P Pin 4 |-------- ICM SCLK/SCL

ESP32-S3 3V3 ------------------------------ ICM NCS
ESP32-S3 GND ------------------------------ ICM AD0

ICM-20948 和 ESP32-S3 必须共地
```

## 5. 机械固定

### 腕部传感器单元

- ICM 放入 `5cm × 3.5cm × 1.8cm` 小盒。
- 盒底贴 2mm EVA。
- 盒子背面贴魔术贴，固定到 3.8cm 腕带。
- 位置：腕横纹向上约 2 到 4cm。
- 盒子画箭头，箭头始终朝向手肘。

### 前臂电源和主控单元

- 第一版把 ESP32、TP4057、SS-12E07G4 开关、TPS61088 和电池放入 `10cm × 8cm` 布艺软袋。
- 前臂使用 5cm 绑带，位置约在腕横纹向上 6 到 10cm，避开肘窝。
- `10cm × 7cm × 2.3cm` 主控盒只用于运输和台架测试，不作为投篮佩戴外壳。
- 袋内电池和主板之间加 EVA 或薄泡棉，防止互相撞击。

## 6. 电源路径和开关

采购变更记录：

```text
H1：充电宝 5V -> 开关 -> ESP32 5V，不需要升压模块
H2 初稿：电池 -> TP4057 -> 开关 -> ESP32
下午同步完整供电链后发现缺少 3.7V 转 5V
追加 TPS61088 固定 5V 模块
```

该缺口是 H1 台架方案切换到 H2 可穿戴方案时的电源架构遗漏，不是固件或数据格式问题。

当前主方案已经改为直接使用高电流机械开关；P-MOS、100k、1k 和 AO3415 只保留为无法确认开关低压载流能力时的回退方案，不属于首版装配 BOM。

当前主方案：

```text
500mAh 电池 B+ -> PH2.0 2P -> TP4057 BAT+
500mAh 电池 B- -> PH2.0 2P -> TP4057 BAT-

TP4057 另一组 BAT+ -> SS-12E07G4 3A开关 -> TPS61088 IN+
TP4057 另一组 BAT- ----------------------> TPS61088 IN-

TPS61088 OUT+ 5V -> ESP32 5V
TPS61088 OUT-    -> ESP32 GND
```

规则：

- SS-12E07G4 直接串在电池正极主路径，标称 3A；实际低压载流能力必须在 20 次开关循环和带载测试中复核。
- 原 SS12D07VG4 0.5A 开关不再用于主电流路径，只作为备用或低电流控制。
- TPS61088 的 EN 不需要作为主开关；EN 关闭只是关闭升压，不是完全断开输出。
- TPS61088 必须选择固定 5V 版，输入覆盖 3.0 到 4.2V，额定输出至少 1A，建议 2A。
- 穿戴版优先选择焊盘版 TPS61088；KF301 螺丝端子版会增加重量和厚度，只建议台架使用。
- 客服确认有“跳线固定 5V”和“电位器调压”两种方式；本项目必须选前者，禁止使用电位器调到 5V 后长期佩戴。
- 客服已确认所选链接为固定电压版本，短接 5V 跳线后输出固定 5V，电位器和 ADJ 不参与调节。
- 3.0 到 4.2V 输入低于 5V 输出，符合该 Boost 模块的输入条件。
- 模块必须有板载输入和输出电容，并在空载时实测约 5.00V。
- TP4057 输出不是 5V，必须经过 TPS61088 升压模块。
- 开关不切换 3.3V。
- TP4057 不具备负载共享；充电时必须关闭负载，USB 烧录或导出时必须断开电池输出，避免双 5V 倒灌。
- 充电时关闭负载，第一版不要把封闭软袋直接放在无人看管的充电环境。

只有 SS-12E07G4 实测出现明显压降、发热或复位时，才回退到低压高边 P-MOS 或 AO3415 离散方案；F5305S 5-36V 模块已排除。

## 6.1 TPS61088 与现有配件兼容性

已选固定 5V TPS61088 版本与本项目其余配件的对应关系：

| 环节 | 参数 | 兼容性 | 条件 |
|---|---|---|---|
| 电池 -> TP4057 | 3.7V 500mAh，1C持续/2C峰值，最大充电1C | 兼容 | 持续放电500mA，峰值1A；过流保护点未知，启动峰值需实测 |
| TP4057 -> 3A开关 | 4.2V 以下，负载约 0.5 到 1A | 兼容 | 开关使用电池正极主路径 |
| 3A开关 -> TPS61088 | 3.0 到 4.2V 输入 | 待实测 | 商品页标称 3A，低压带载、压降和温升仍需验证 |
| TPS61088 -> ESP32 | 固定 5V 输出 | 兼容 | 接 ESP32 5V 与 GND |
| ESP32 -> ICM | 3.3V、GPIO8、GPIO9 | 兼容 | 不改变 NCS、AD0 和 I2C 基线 |
| PH2.0 2P -> 电池 | 约 0.5 到 1A 稳态 | 兼容 | 峰值上电电流需实测 |
| PH2.0 4P -> ICM | 4 根信号和电源线 | 兼容 | 线序固定 VCC/GND/SDI-SDA/SCLK-SCL |
| TPS61088 -> 前臂软袋 | 40 × 22mm，焊盘版 | 兼容 | 优先焊盘版，端子版更厚 |

到货与装配前确认：

- [x] 商品 SKU 为 `TPS61088(5V)` 固定电压版本。
- [x] 固定 5V 通过短接 5V 跳线实现，不依赖电位器长期保持。
- [ ] 到货后确认是焊盘版还是 KF301 螺丝端子版；焊盘版优先用于佩戴，端子版仅用于台架。
- [x] 电池保护板持续放电 `1C = 500mA`，峰值 `2C = 1A`，最大充电 `1C = 500mA`。
- [ ] 过流保护点未知，TPS61088 启动峰值不能长期接近或超过 1A。
- [ ] 不要因为 TPS61088 标称 2A 就用 500mAh 电池长期跑满 2A；当前电池持续上限只有 500mA。
- [ ] 模块 EN 不作为主电源开关，主开关仍使用 SS-12E07G4。
- [ ] 输出先空载测 5.00V，再带 ESP32 启动测试，不得低于约 4.85V。
- [ ] 采样率按 `210-240Hz` 或中位采样间隔 `4.0-4.8ms` 验收。

## 7. 应力释放

- 线束两端各留 1 到 2cm 缓冲弯。
- 每 3 到 5cm 用纸胶带、魔术贴或医用胶带固定。
- PH2.0 插头前后不能直接承受传感器惯性拉力。
- 传感器盒入口处先固定线束，再进入盒子。
- 前臂软袋入口处固定线束，USB-C 口不受线缆拉力。
- 快速挥臂时，插头、焊点和 ICM 排针不能出现可见位移。

## 8. 万用表检查

### 断电检查

- [ ] VCC 对 GND 不短路。
- [ ] ICM SDI/SDA 对 GND 不短路。
- [ ] ICM SCLK/SCL 对 GND 不短路。
- [ ] VCC 与 ICM SDI/SDA 不导通。
- [ ] VCC 与 ICM SCLK/SCL 不导通。
- [ ] NCS 与 3V3 导通。
- [ ] AD0 与 GND 导通。
- [ ] PH2.0 4P 两端线序一致。
- [ ] 电池正负极没有接反。

### 上电检查

- [ ] ICM VCC 约 3.3V。
- [ ] NCS 约 3.3V。
- [ ] AD0 约 0V。
- [ ] ESP32 与 ICM 共地。
- [ ] 升压模块输出约 5.0V。
- [ ] ESP32 启动和记录期间，TPS61088 输出不低于约 4.85V。
- [ ] SS-12E07G4 闭合时，开关两端压降在带载工况下可接受且无明显发热。
- [ ] ESP32 3V3 测试点约 3.3V。

## 9. H2 测试步骤

详细执行顺序以 `docs/hardware/H2_ASSEMBLY_RUNBOOK.md` 为准。本节保留验收门槛。

### 测试 0：电池和 TP4057

```text
1. 断电检查电池极性。
2. 确认两块 500mAh 电池电压在 3.0 到 4.2V。
3. 确认 TP4057 同极性 BAT 焊盘导通，BAT+ 与 BAT- 不导通。
4. 只接电池和 USB-C 5V，不接 ESP32、TPS61088 或负载。
5. 观察充电红灯、电池电压上升、无明显发热；充满后绿灯亮。
```

通过条件：

- [ ] 不接反。
- [ ] 充电电流和温升无异常。
- [ ] 充满后约 4.2V，绿灯亮。

### 测试 A：接口静态检查

```text
1. 只使用 USB 给 ESP32 供电。
2. 不接电池和升压模块。
3. 软件读取 WHO_AM_I。
4. 预期返回 0xEA。
5. 固定 I2C 50kHz 和地址 0x68。
```

通过条件：

- [ ] 地址 `0x68`。
- [ ] `WHO_AM_I=0xEA`。
- [ ] 无通信异常。
- [ ] 电源切换后 GPIO48 RGB 蓝色常亮；蓝灯不亮时按一次 RST 后再确认。

### 测试 A2：TPS61088 和 ESP32 启动

```text
1. 校准 TPS61088 的固定 5V 跳线，不接 ESP32。
2. 空载测量输出约 5.00V。
3. 接 ESP32 5V 和 GND，打开开关。
4. 确认 GPIO48 RGB 蓝色常亮，不亮时按一次 RST。
5. 执行一次 10 秒记录并观察电压、复位和开关温升。
```

通过条件：

- [ ] 空载约 5.00V。
- [ ] 启动和记录期间不低于约 4.85V。
- [ ] 连续开关 20 次无复位、无电池保护板跳闸。
- [ ] SS-12E07G4 无明显发热。

### 测试 B：10 秒静止测试

```text
1. 固定传感器和线束。
2. 保持静止。
3. 使用 F4 固件短按 BOOT 记录 10 秒。
4. 导出并检查数据。
```

通过条件：

- [ ] 采样率在 `210-240Hz`，或中位采样间隔在 `4.0-4.8ms`。
- [ ] 最大采样间隔不超过 10ms。
- [ ] 无复位。
- [ ] 无全零。
- [ ] 无固定饱和。
- [ ] 无削顶。

### 测试 C：小幅动态测试

```text
1. 缓慢屈伸腕部、旋转前臂和摆臂。
2. 检查连接器和线束是否松动。
3. 再次执行 10 秒记录。
```

通过条件：

- [ ] 无复位。
- [ ] 无全零。
- [ ] 无固定饱和。
- [ ] 无削顶。
- [ ] 最大采样间隔不超过 10ms。
- [ ] 接头和焊点没有位移。

### 测试 D：真实投篮门槛

只有在测试 0、A、A2、B、C 全部通过后，才允许进入真实投篮采集。

## 10. 照片要求

实物照片放入 `photos/H2/`，不得包含姓名、手机号、地址或订单页面。

必须提交：

- [ ] ESP32 和 ICM 接线全景。
- [ ] PH2.0 4P 两端插头和线序。
- [ ] ICM 的 NCS 和 AD0 固定位置。
- [ ] 电池和 TP4057 焊接位置。
- [ ] 开关和升压模块位置。
- [ ] 腕部传感器单元正面。
- [ ] 腕部传感器单元背面和 EVA。
- [ ] 前臂电池和主控软袋。
- [ ] 实际佩戴正面照片。
- [ ] 线束应力释放特写。
- [ ] 万用表电压或通断检查照片。

照片提交后，在本文件的对应复选框打勾。

## 11. 已知风险

- TPS61088 已到货，但固定 5V 跳线、空载输出和 ESP32 启动压降尚未实测。
- TPS61088 必须选固定 5V SKU，不能用只有电位器且没有电压指示的版本。
- 首版只需要 1 个 TPS61088；第二个只作为备用，不影响功能验收。
- SS12D07VG4 常见额定值约 0.5A；在数据手册确认达到 1A 前，不得用于升压输入主路径。当前只作为备用或低电流控制。
- 首版不使用 P-MOS、100k、1k 或 AO3415；只有直接 3A 开关实测不合格时才切换到该回退方案。
- SS-12E07G4 的标称值来自商品页，低压 DC 带载、接触电阻、压降和温升必须在装配后实测。
- H2 实物尚未装配，所有机械和测试结果均为待验证。
- `10cm × 8cm` 软袋对前臂偏大，真实投篮时可能晃动。
- `10cm × 7cm × 2.3cm` 主控盒不适合佩戴，只能做收纳和台架。
- 26AWG 线只有黑红两色，ICM `SDI/SDA` 和 `SCLK/SCL` 必须靠标签区分。
- TP4057 是充电板，需要确认 Type-C 口在前臂软袋中的可访问性。
- 快速动作时，PH2.0 插头可能承受拉力，必须实际验证应力释放。
- NCS 和 AD0 如果焊点断开，可能出现地址漂移或通信异常。
- 任何接口变更都必须由软件对话批准并更新基线文件。

## 12. H2 完成判定

- [ ] BOM 已确认并记录采购状态。
- [ ] 接线图和连接器型号已确认。
- [ ] 固定方式和应力释放已实装。
- [ ] TP4057 独立充电测试已通过，电池充满约 4.2V。
- [ ] 电源路径和开关位置已实测。
- [ ] TPS61088 空载调到 5.00V，并完成 ESP32 启动压降测试。
- [ ] SS-12E07G4 连续开关 20 次无 ESP32 复位、无电池保护板跳闸。
- [ ] 照片已提交。
- [ ] 万用表检查已通过。
- [ ] 10 秒静止测试已通过。
- [ ] 小幅动态测试已通过。
- [ ] 已知风险已记录。

在上述项目全部完成前，H2 状态保持为“装配与验证中”，不得标记为完成。

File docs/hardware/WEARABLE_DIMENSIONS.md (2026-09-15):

# Wearable Dimensions and Fit Check

Baseline: `KB-2026-09-15-H1-F4-I1`
Hardware revision: `H2`

本文件用于确认第一版可穿戴设备的物理包络。已购买物料尺寸按商品规格记录，未实测的电路板尺寸标记为暂估，必须到货后用卡尺复核。

## 1. 单体尺寸

| 部件 | 尺寸 | 状态 | 说明 |
|---|---:|---|---|
| ICM-20948 模块 | `15.32 × 26.54mm`，PCB 厚约 1.6mm | 商家尺寸图 | 不含焊接线高度 |
| ICM 传感器盒 | 50 × 35 × 18mm | 已确认 | 当前第一版外壳 |
| 传感器盒 + EVA | 50 × 35 × 20mm | 计算值 | 上下各 1mm，按 2mm EVA 计算 |
| ESP32-S3 开发板 | PCB `57.15 × 25.4mm`；含 Type-C 总体约 `63.611 × 27.94mm` | 商家尺寸图 | 不含排针高度；布局按 63.6 × 28mm 预留 |
| TP4057 充电板 | PCB `11.1 × 10.4mm`，不含 Type-C；总包络约 `14 × 11 × 5mm` | 商家尺寸图 + 预留 | Type-C 突出部分和焊线会增加长度与厚度 |
| TPS61088 模块 | PCB `22 × 40mm`；焊盘版厚约 `7 到 9mm`，KF301 端子版厚约 `11 到 14mm` | 商家尺寸图 + 预留 | 焊盘版约 5.4g，端子版约 10g；穿戴优先焊盘版 |
| SS-12E07G4 开关 | 约 19.6 × 12.8 × 6.5mm，手柄另加约 4mm | 已确认 | 使用短脚版本优先 |
| 3.7V 602535 电池 | 35 × 25 × 6mm | 已确认 | 500mAh 软包 |
| PH2.0 连接器 | 插头外加约 5 到 8mm | 暂估 | 需要预留拔插和应力释放空间 |

## 2. 腕部传感器单元

第一版包络：

```text
长度（沿前臂方向）：约 50mm
宽度（横向前臂方向）：约 35mm
厚度：约 20 到 22mm
固定带：38mm 宽腕带
```

建议位置：

```text
腕横纹向手肘方向 2 到 4cm
盒子箭头朝向手肘
传感器轴方向保持每次一致
```

评估：

- 宽度 35mm 小于 38mm 腕带，能够被腕带覆盖住主要区域。
- 长度 50mm 比 38mm 绑带更宽，需要魔术贴辅助固定，不能让盒子两端翘起。
- 厚度 18mm 的盒子偏厚。第一版静态和动态测试可以接受，最终目标建议降到 12 到 15mm。
- 传感器不能放在手背或腕横纹正上方，避免投篮时碰撞篮球。

## 3. 前臂电源和主控单元

第一版使用 `100 × 80mm` 布艺软袋。

平面上尽量只铺一层，推荐排列：

```text
100mm 长度方向
+------------------------------------------------+
| TPS61088 40×22 | 开关 20×13 | TP4057 11×10   |
| ESP32 64×28    | 电池 35×25                 |
+------------------------------------------------+
80mm 宽度方向
```

该排列的总面积约为：

```text
TPS61088: 880mm²
ESP32:    1792mm²
电池:      875mm²
TP4057:    110mm²
开关:      260mm²
合计:      3917mm²
```

软袋面积：

```text
100 × 80 = 8000mm²
```

结论：

- 单层铺放面积足够，仍有余量放导线和缓冲泡棉。
- 最大厚度由 TPS61088 模块决定，目标整袋厚度控制在 18 到 22mm。
- 如果 ESP32、TPS61088 和电池叠成三层，厚度可能超过 30mm，不建议。
- 80mm 宽对大多数前臂接近或略宽于前臂横向尺寸，需要魔术贴底座和 5cm 绑带配合。
- ESP32 开发板含 Type-C 总长约 `63.6mm`，因此不能用 `70 × 50mm` 小袋装下当前套件。
- 第一版 `100 × 80mm` 软袋与当前开发板尺寸匹配；要缩到约 `70 × 50mm`，必须先做定制 PCB 或换成更小的主控板。

## 4. 绑带尺寸检查

已购买：

```text
腕带：38mm 宽 × 50cm 长
前臂带：50mm 宽 × 50cm 长
```

适用范围：

- 38mm × 50cm 腕带适合常见 14 到 20cm 腕围，50cm 可以重叠固定。
- 50mm × 50cm 前臂带适合常见 22 到 32cm 前臂围，50cm 足够缠绕并留出调整余量。
- 前臂软袋宽 80mm，50mm 绑带不能完全覆盖整个袋子，必须在袋子背面加魔术贴或防滑底。

## 5. 穿戴总包络

当前第一版目标：

```text
腕部单元：50 × 35 × 22mm
前臂单元：100 × 80 × 22mm
腕部位置：腕横纹上方 2 到 4cm
前臂位置：腕横纹上方 5 到 10cm
```

总重量目标：

```text
腕部传感器单元：不超过 20g
前臂电源和主控单元：不超过 60g
整机：不超过 80g
```

## 6. 到货后必须实测

用卡尺或直尺记录：

- [ ] ESP32-S3 板长、宽、厚，含排针和 USB 口；商家图已给出 PCB 和 Type-C 外廓。
- [ ] ICM-20948 模块实际长宽和焊线后的最大厚度；商家图尺寸为 15.32 × 26.54mm。
- [ ] ICM 传感器盒实际外尺寸和内尺寸。
- [ ] TPS61088 模块长、宽、高，含端子和电感。
- [ ] 确认所收 TPS61088 是焊盘版还是 KF301 端子版，并实测最高点。
- [ ] TP4057 模块含 Type-C 的总长、总宽、总高；商家图 PCB 为 11.1 × 10.4mm。
- [ ] 电池长、宽、厚。
- [ ] 开关含手柄的总高度。
- [ ] 腕围。
- [ ] 前臂中段围度。
- [ ] 腕横纹到肘窝的距离。

## 7. 穿戴验收

- [ ] 腕部传感器不压腕横纹。
- [ ] 手掌弯曲和握球时，传感器盒不顶住篮球。
- [ ] 前臂软袋不覆盖肘窝。
- [ ] 快速摆臂时，两个单元不互相拉扯。
- [ ] 线束不会限制腕部和前臂动作。
- [ ] 穿戴后 3 分钟没有明显压痛、滑动或皮肤过热。
- [ ] 设备总重量不超过目标范围。

## 8. 当前结论

第一版尺寸可以继续制作，属于“偏大但可用”的可穿戴原型。

- 腕部传感器单元当前偏厚，最终必须缩小。
- 前臂软袋可以容纳全部模块，但必须单层布置；当前 10×8cm 尺寸对开发板版本是必要的。
- 需要额外魔术贴或防滑底，不能只靠 5cm 绑带压住 80mm 宽的软袋。
- ESP32 和 ICM 模组实测后，需要重新更新本文件的暂估值。

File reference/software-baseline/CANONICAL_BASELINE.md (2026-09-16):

# Kineshoot 统一基线

基线编号：KB-2026-09-15-H1-F4-I1

状态：冻结

本文件是两个对话共同使用的唯一基准。若硬件设计、引脚、I2C 地址或软件协议与本文冲突，以本文为准，除非双方明确批准新的版本号。

## 一、基线原则

```text
软件定义接口和数据格式
硬件负责实现、固定和验证
硬件不能静默修改软件依赖的地址、引脚、电压或协议
```

任何接口变化必须：

1. 提交变更原因。
2. 更新 `docs/INTERFACE.md`。
3. 更新 `project.json`。
4. 增加接口或软件版本号。
5. 重新完成静止和动态验收。

## 二、硬件基线 H1

```text
ESP32-S3-DevKitC-1，N16R8
ICM-20948
六线直连
充电宝 5V 供电
USB-C 数据口用于烧录和导出
```

板载接口补充：

```text
BOOT       = GPIO0
RST        = 硬件复位
RGB LED    = WS2812B，GPIO48
电源红灯   = 不可控，仅表示供电
USB-C 接口 = CH340 串口口 + 原生 USB-OTG 口
```

测试规则：

- 始终使用电脑识别为 `COM5` 的那个 USB-C 口进行烧录和串口调试。
- 充电宝测试优先使用同一个 USB-C 口，只改变供电源，不改变端口。
- 电源红灯亮只能说明板子有电，不能说明固件已经运行或正在记录。
- 无绳状态使用 GPIO48 的 WS2812B 提供反馈。

固定接线：

```text
ESP32 GPIO8  -> ICM SDI / SDA
ESP32 GPIO9  -> ICM SCLK / SCL
ESP32 3V3    -> ICM VCC
ESP32 GND    -> ICM GND
ESP32 3V3    -> ICM NCS
ESP32 GND    -> ICM AD0
```

固定通信参数：

```text
I2C address: 0x68
I2C clock:   50 kHz
WHO_AM_I:    0xEA
```

明确禁止：

```text
0x69 作为长期主地址
0x0C 作为 ICM 主地址
AD0 悬空
NCS 悬空
3.3V 电源路径串入拨动开关
```

H1 是功能基线，不是最终机械版本。H1 仍依赖人工防止线缆受力。

## 三、软件基线 F4

固件目录：

```text
firmware/imu_flash_logger_v4/
```

配置：

```text
加速度              +/-16g
陀螺仪              +/-2000dps
加速度 DLPF         111.4Hz
陀螺仪 DLPF         119.5Hz
加速度 ODR          约 225Hz
陀螺仪 ODR          约 220Hz
记录时长             10 秒
采样期间             RAM 缓冲
记录结束             批量写入 LittleFS
运行状态触发          短按 BOOT
串口状态             USB CDC On Boot = Enabled
```

F4 不读取磁力计，只保存：

```text
timestamp_us
ax_mg
ay_mg
az_mg
gx_dps
gy_dps
gz_dps
temp_c
```

## 四、标准操作流程

### 无绳记录

```text
1. 连接充电宝
2. 确认 BOOT 没有被按住
3. 检查 RGB 是否蓝色常亮
4. 如果蓝灯不亮，按一次 RST
5. 必须确认 RGB 蓝色常亮，再进入主循环
6. 等待约 2-5 秒
7. 短按 BOOT 并立即松开
8. RGB 变为红色
9. 前 1-2 秒保持静止
10. 执行测试动作
11. 等待 10 秒记录结束
12. 看到 RGB 绿色后恢复蓝色，表示写盘完成
13. 断开充电宝
```

### 导出

```text
1. 连接电脑 USB
2. 松开 BOOT 后按一次 RST
3. 确认 RGB 蓝色常亮
4. 打开串口监视器并确认 IMU_FLASH_V4_READY
5. 关闭串口监视器
6. 运行专用导出批次
```

### 供电源切换规则

从电脑切换到充电宝，或从充电宝切换回电脑后：

```text
先检查 RGB 蓝色状态
蓝灯亮时可以直接继续
蓝灯不亮时按一次 RST
确认蓝色常亮后再开始 BOOT 记录或导出
```

不可控红色电源灯亮只能说明开发板有电，不能说明 F4 已经运行。

导出后必须得到：

```text
capture_XXX.csv
capture_XXX.meta.json
```

元数据必须包含：

```text
hardware_revision
software_revision
interface_revision
firmware_protocol
mount_position
test_type
operator
git_sha
```

## 五、数据基准

### 静止基准

```text
data/flash_v4_static_retest_001.csv
rows                    2269
sample rate             226.88 Hz
maximum interval        6.244 ms
gaps >= 10 ms           0
errors                  0
resets                  0
```

### 加强动作基准

```text
data/flash_v4_strength_retest_002.csv
rows                    2269
sample rate             226.88 Hz
maximum interval        6.357 ms
gaps >= 10 ms           0
errors                  0
resets                  0
```

### 六轮连续性基准

```text
directory               data/raw/20260916/
rounds                  6
rows per round          2269-2270
sample rate             226.846-226.931 Hz
maximum interval        5.844-6.350 ms
gaps >= 10 ms           0
sequence discontinuities 0
errors                  0
resets                  0
```

### 三组小幅动态基准

```text
directory               data/raw/20260916/
rounds                  3
rows per round          2269-2270
sample rate             226.854-226.940 Hz
maximum interval        5.843-6.360 ms
gyro magnitude max      263.49-388.66 dps
gaps >= 10 ms           0
errors                  0
resets                  0
clipped samples         0
```

### 充电宝与 BOOT 供电验证

```text
directory               data/raw/20260916/
files                   powerbank_boot_run01_round01-03.csv
power_source            power_bank
trigger_source          boot_button
status                  power and write pass
motion status           no motion in the intended 2-5 second window
```

### 充电宝 BOOT 投篮动作基准

```text
directory               data/raw/20260916/
files                   powerbank_boot_motion_run02_round01-03.csv
power_source            power_bank
trigger_source          boot_button
round 1 gyro max        175.98 dps
round 2 gyro max        271.98 dps
round 3 gyro max        466.36 dps
round 3 accel max       3270.16 mg
gaps >= 10 ms           0
errors                  0
resets                  0
clipped samples         0
```

### 五组静止对照 Run 02

```text
directory               data/raw/20260916/
files                   static_control_run02_round01-05.csv
power_source            power_bank
trigger_source          boot_button
rows per round          2269-2270
sample rate             226.845-226.939 Hz
maximum interval        5.844-6.331 ms
gyro after 1s mean      1.227-1.543 dps
gaps >= 10 ms           0
errors                  0
resets                  0
clipped samples         0
```

### 动作速度对照 Run 03

```text
directory               data/raw/20260916/
files                   comparison_run03_static.csv
                        comparison_run03_slow.csv
                        comparison_run03_medium.csv
                        comparison_run03_fast.csv
power_source            power_bank
trigger_source          boot_button
slow gyro max           198.50 dps
medium gyro max         425.75 dps
fast gyro max           433.32 dps
maximum interval        5.844-6.266 ms
gaps >= 10 ms           0
errors                  0
resets                  0
clipped samples         0
```

### 模拟投篮基准

```text
data/flash_v4_sim_shot_006.csv
data/flash_v4_shot_trial_007.csv
data/flash_v4_shot_trial_008.csv
data/flash_v4_shot_trial_009.csv
```

历史无效数据：

```text
早期 v1 数据         保留用于问题分析，不作为当前基准
v3 数据              保留用于 Flash 停顿对照
空 capture_010       已删除
截断 capture_011     保留分析副本，不作为有效数据
```

## 六、验收门槛

静止和动作测试必须全部满足：

```text
采样率 >= 200 Hz
最大采样间隔 <= 10 ms
超过 20 ms 缺口 = 0
序号跳变 = 0
错误 = 0
复位 = 0
全零段 = 0
固定饱和段 = 0
削顶样本 = 0
```

真实投篮前还要满足：

```text
ESP32 和 ICM 位于同一硬质底板
四根信号线有应力释放
USB 线不拉主板接口
电源开关不经过 3.3V
静止测试通过
动态测试通过
```

## 七、给硬件对话的固定约束

硬件代码和记录放在独立仓库：

```text
https://github.com/koreever66/kineshoot-initial-debug-v1
```

软件、接口和数据基线以本仓库为准：

```text
https://github.com/koreever66/kineshoot-initial-debug-v2
```

硬件型号、连接器和机械结构可以变化，但 H2 必须继续满足：

```text
GPIO8 = SDA
GPIO9 = SCL
NCS = 3V3
AD0 = GND
ICM VCC = 3V3
GND 共地
地址 = 0x68
```

硬件对话完成 H2 后，必须提交：

```text
硬件版本
接线图
连接器型号
固定方式
电源路径
开关位置
应力释放方式
实物照片
测试结果
已知风险
```

## 八、版本升级规则

以下变化必须升级版本：

```text
引脚变化
I2C 地址变化
电压变化
量程变化
采样率变化
数据格式变化
文件命名变化
触发方式变化
```

机械结构调整可以不改变 I1 和 F4，但必须记录新的硬件版本，例如 H2。

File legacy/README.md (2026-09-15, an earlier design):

# Legacy v1 Archive

本目录只保存旧的 v1 固件、工具和数据。

当前软件以 `koreever66/kineshoot-initial-debug-v2` 为准。

当前分支为 `codex/software-data`。

当前基线为 `KB-2026-09-15-H1-F4-I1`。

不要使用 legacy 中的旧固件采集。

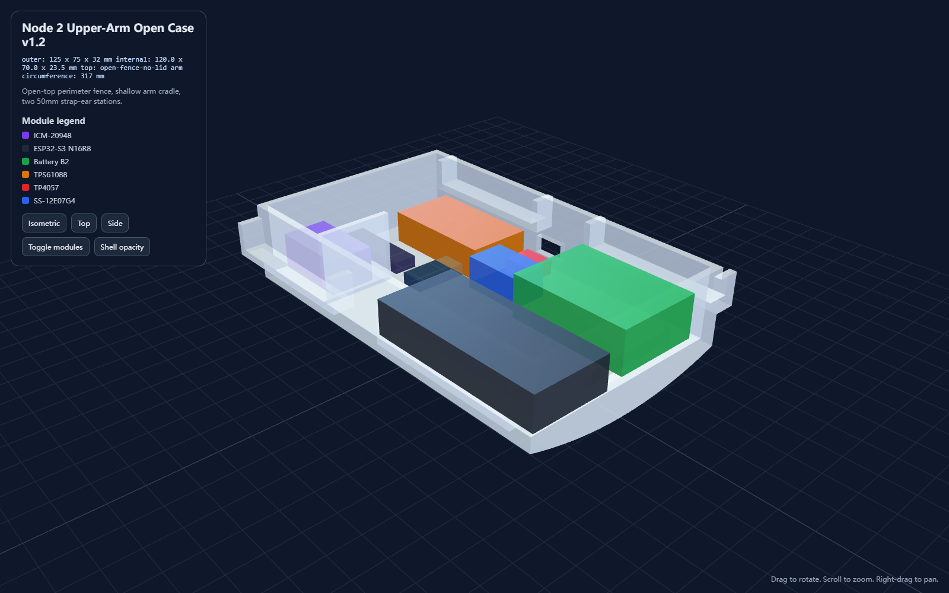
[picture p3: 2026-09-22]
docs/hardware/design/node2_open_top_v1/preview_iso.png

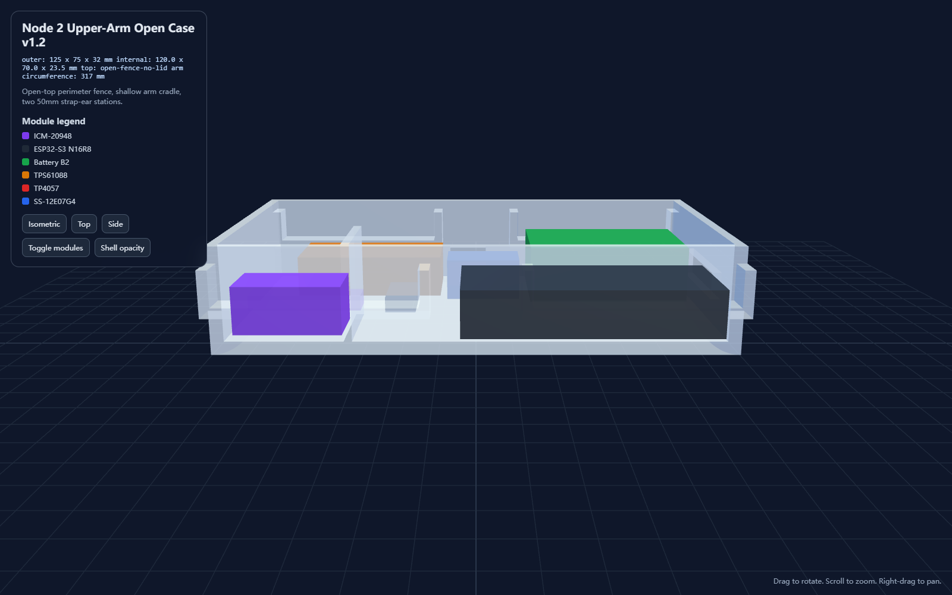
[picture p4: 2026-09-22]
docs/hardware/design/node2_open_top_v1/preview_side.png

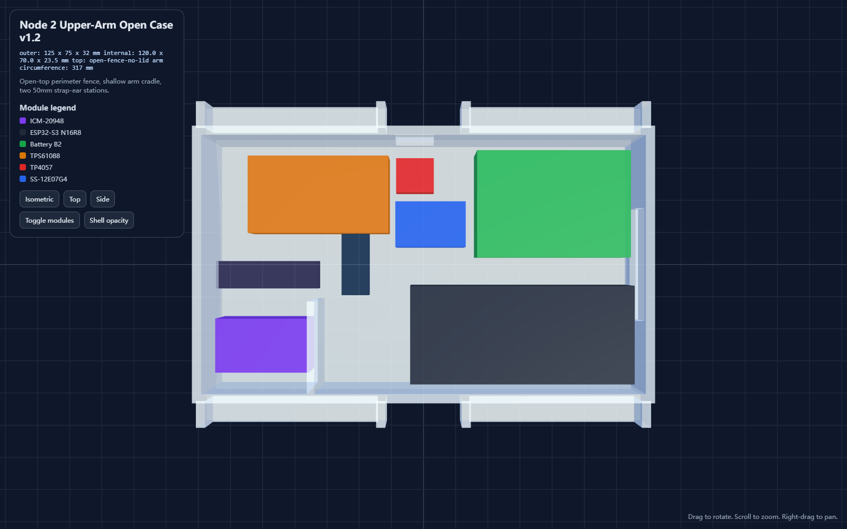
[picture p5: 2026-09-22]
docs/hardware/design/node2_open_top_v1/preview_top.png

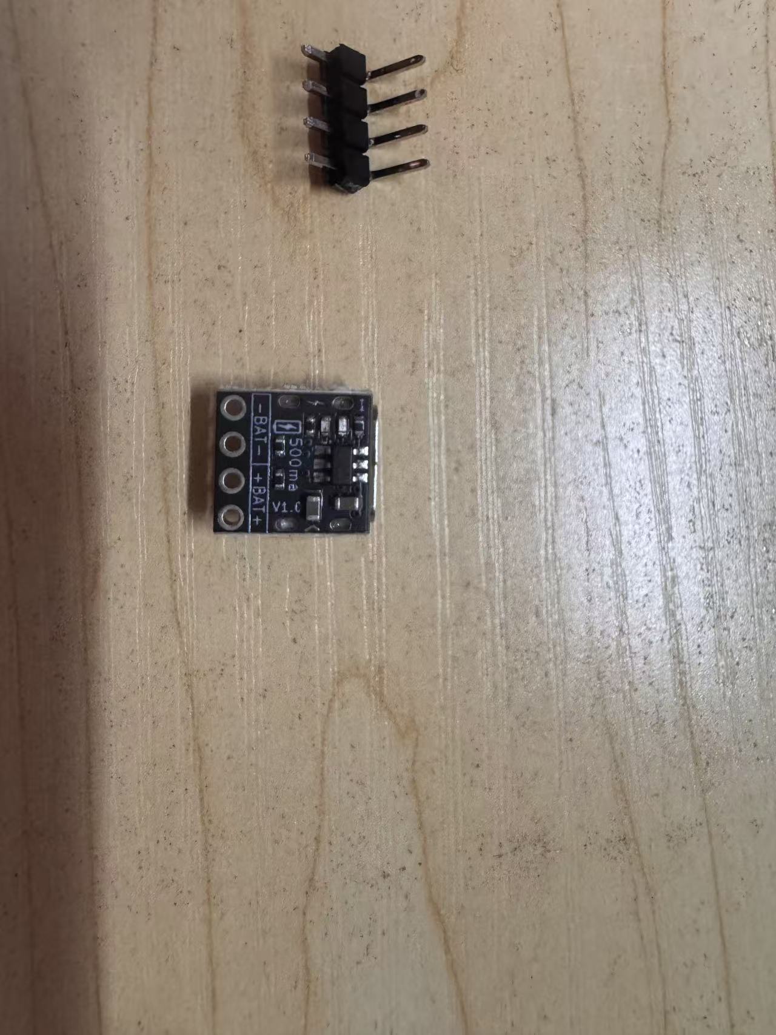
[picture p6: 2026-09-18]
photos/H2/2026-09-18_tp4057_500ma.jpg

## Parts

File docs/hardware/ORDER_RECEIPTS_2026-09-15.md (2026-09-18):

# 2026-09-15 订单与物料清单

整理日期：2026-09-16

说明：

- 金额按订单页“实付”或“先用后付待扣款”统计。
- 已退款成功的订单不计入。
- 商品截图中的姓名、电话和地址没有写入仓库。

## 一、有效订单

| 状态 | 物品 | 规格与数量 | 金额 |
|---|---|---|---:|
| 已签收 | ESP32-S3 开发板 | N16R8，向下焊，含 Type-C 数据线，1 套 | ¥34.40 |
| 已签收 | ICM-20948 | MCU-20948 九轴模块，1 个 | ¥48.94 |
| 已签收 | 面包板 | 400 孔 MB102，1 个 | ¥2.68 |
| 已签收 | 杜邦线 | 2.54mm 母对母，40P，20cm，1 排 | ¥4.20 |
| 已到货 | TP4057 充电板 | TP4057-500mA 版本，Type-C；为避免选错规格购买 2 个 | ¥5.94 |
| 已到货 | TPS61088 模块 | TPS61088(5V) 固定电压版，1 个 | ¥11.32 |
| 已到货 | 高电流开关 | SS-12E07G4，1P2T，3A，5 只装 | ¥4.89 |
| 已到货 | 备用低电流开关 | SS12D07VG4，1P2T，柄高 4mm，10 只装 | ¥2.40 |
| 已到货 | 电池 | 602535，3.7V 500mAh，带保护板，1C持续/2C峰值，2 个 | ¥18.76 |
| 已到货 | PH2.0 2P | 公母一套，20cm，2 套 | ¥3.20 |
| 已到货 | PH2.0 4P | 公母一套，20cm，5 套 | ¥10.36 |
| 已到货 | 柔性线 | 26AWG，0.13 平方，黑色 2 米 | ¥3.50 |
| 已到货 | 柔性线 | 26AWG，0.13 平方，红色 2 米 | ¥3.50 |
| 已到货 | 热缩管 | 黑色，200 条，8 种型号 | ¥7.80 |
| 已到货 | EVA 泡棉 | 2mm 厚，2.5cm 宽，5 米 | ¥4.80 |
| 已到货 | 传感器盒 | 5 × 3.5 × 1.8cm，2 个装 | ¥2.28 |
| 已到货 | 主控收纳盒 | 10 × 7 × 2.3cm，2 个装 | ¥3.18 |
| 已到货 | 元件盒 | 3# 红色，1 个 | ¥2.60 |
| 已到货 | 前臂绑带 | 5cm 宽，50cm 长，1 条 | ¥5.00 |
| 已到货 | 腕部绑带 | 3.8cm 宽，50cm 长，1 条 | ¥4.80 |
| 已到货 | 运动护腕 | 黑色 1 只 + 蓝色 1 只 | ¥6.50 |
| 已到货 | 电池软袋 | 布艺拉链袋，10 × 8cm，1 个 | ¥2.10 |

## 二、金额统计

```text
有效订单数量：22 项
总成本：约 ¥193.15
当前已实付：约 ¥167.89
先用后付待扣款：约 ¥25.26
```

先用后付待扣款包括：

```text
602535 电池 2 个：¥18.76
运动护腕：¥6.50
```

## 三、退款或不计入订单

```text
20P 母对母杜邦线：¥2.85，已退款成功，不计入 BOM
```

## 四、当前可用物料

已到货并可进入装配：

- ESP32-S3-N16R8
- ICM-20948
- 400 孔面包板
- 40P 母对母杜邦线
- TPS61088 固定 5V 模块
- TP4057-500mA 充电板
- SS-12E07G4 3A 开关
- 602535 电池
- PH2.0 2P 和 4P 连接器
- 26AWG 红线和黑线
- 热缩管、EVA 泡棉
- 传感器盒、前臂软袋和绑带

到货确认日期：2026-09-18。到货只代表可装配，不代表电源链、焊接、机械固定或动态测试已经通过。

TPS61088 不是最初 H1 充电宝方案的采购项，而是今天下午与软件端同步完整供电链后，确认 H2 电池路径缺少 `3.7V -> 5V` 升压后追加的采购。

## 五、仍然缺的采购或确认项

- [x] 电池保护板参数：持续放电 `1C = 500mA`，峰值 `2C = 1A`，最大充电 `1C = 500mA`。
- [ ] 过流保护点未知；TPS61088 启动峰值仍需实测，不能超过 1A 太多。
- [ ] 万用表通断档是否可用。
- [ ] 魔术贴、纸胶带、扎带或医用胶带是否齐全。

## 六、按当前订单可完成的能力

以下项目截至 2026-09-18 尚未执行，复选框保持为空；到货不等于装配或验证完成。

- [ ] ESP32 和 ICM 面包板验证。
- [ ] TP4057 与电池充电测试。
- [ ] 3A 开关直连 TPS61088 供电测试。
- [ ] TPS61088 固定 5V 输出测试。
- [ ] 腕部传感器线束焊接和 PH2.0 4P 连接。
- [ ] PH2.0 2P 电池连接器焊接。
- [ ] 前臂软袋和腕部绑带第一版装配。

## 七、不可省略的验收

- [ ] 固定 5V 模块必须使用 5V 跳线，不使用电位器调压。
- [ ] 主电源开关使用 SS-12E07G4 3A 直连电池正极。
- [ ] TPS61088 输出空载约 5.00V。
- [ ] ESP32 启动和记录时输出不低于 4.85V。
- [ ] ICM 仍由 ESP32 3V3 供电，I2C 固定 50kHz、地址 0x68、WHO_AM_I 0xEA。

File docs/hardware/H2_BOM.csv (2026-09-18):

状态 | 物品 | 规格 | 数量 | 用途 | 参考链接或来源 | 备注
已到货 | ESP32-S3 开发板 | N16R8 | 1 | 主控 | 历史采购 | 已有并完成面包板点亮
已到货 | ICM-20948 | 九轴 IMU | 1 | 传感器 | 历史采购 | 已有并完成面包板通信
已到货 | 柔性硅胶线 | 26AWG 0.13平方 | 黑色2米+红色2米 | H2 线束 | 拼多多 888568040924 | 红黑两色；黑色信号线必须贴标签
已到货 | PH2.0 4P 公母带线 | 2.0mm 20cm | 5套 | IMU 至 ESP32 | 拼多多 959817915240 | VCC/GND/SDI-SDA/SCLK-SCL；NCS和AD0在传感器端固定
已到货 | PH2.0 2P 公母带线 | 2.0mm 20cm | 2套 | 电池至TP4057 | 拼多多 959817915240 | 电池端优先母头
已到货 | 备用低电流开关 | SS12D07VG4 1P2T 柄高4mm | 10个 | 备用或低电流控制 | 拼多多 816400229649 | 常见额定约0.5A；不得用于升压输入主路径
已到货 | 高电流滑动开关 | SS-12E07G4 1P2T 3A 250VAC/5A 125VAC 接触电阻≤50mΩ | 1个 | 首版主开关，直接控制电池正极主路径 | 拼多多 715608530062 | 确认ON-ON保持型；商品页标称3A；低压带载、压降和温升必须实测
已到货 | 热缩管 | 黑色8种型号混合套装 | 1盒 | 焊点绝缘 | 拼多多 104615947320 | 覆盖每个焊点
已到货 | TP4057 充电模块 | TP4057-500mA Type-C 4.2V | 1个 | 500mAh电池充电 | 拼多多 970183834102 | 已确认背板500mA标识；首版不使用第二块作为负载输出
已到货 | TPS61088升压模块 | 固定5V输出 3.0-4.2V输入 2A额定 板载输入输出电容 | 1个 | 电池给ESP32供电 | 拼多多 910993013736 | 已到货；必须短接固定5V跳线；空载和带载未测
不用于首版 | P沟道高边开关模块 | 明确支持3.0-4.2V 1A以上 有可用EN或CTRL端 | 0个 | SS-12E07G4实测不合格时的回退方案 | 不采购 | 禁止购买F5305S 5-36V输出模块；不得为了备用而先行采购
不采购 | P沟道MOSFET | AO3415 SOT-23 -20V -4A 低阈值 | 0只 | SS-12E07G4实测不合格时的离散回退方案 | 拼多多 854394853241 | 首版不使用
不采购 | 电阻 | 100k和1k 1/4W | 0只 | 离散P-MOS栅极控制 | 不采购 | 只有切换到AO3415回退方案时才需要
已到货 | 锂电池 | 3.7V 602535 500mAh带保护板 | 2个 | 系统电源 | 拼多多 375621436635 | 持续放电1C=500mA；峰值2C=1A；最大充电1C=500mA；过流保护点未知
已到货 | 电池软袋 | 布艺平口拉链袋10cm×8cm | 1个 | 前臂电源单元 | 拼多多购买记录 | 第一版稍大但可用
已到货 | EVA背胶泡棉 | 2mm厚2.5cm宽5米 | 1卷 | 缓冲和防滑 | 拼多多 813336805787 | 隔开皮肤与硬边
已到货 | ICM传感器盒 | 5cm×3.5cm×1.8cm | 2个 | 腕部传感器外壳 | 拼多多 758764927994 | 低矮盒可佩戴
已到货 | 主控收纳盒 | 10cm×7cm×2.3cm | 2个 | 运输和台架测试 | 拼多多 636933138424 | 不作为投篮佩戴外壳
已到货 | 腕部弹力绑带 | 3.8cm×50cm | 1条 | 固定ICM单元 | 拼多多 773043261581 | 腕横纹上方2到4cm
已到货 | 前臂弹力绑带 | 5cm×50cm | 1条 | 固定前臂电源单元 | 拼多多 773043261581 | 避开肘窝
已确认 | 万用表 | 支持通断档 | 1台 | 焊点和电压检查 | 自备或实验室 | 开始焊接和上电前必须具备
已确认 | 魔术贴/纸胶带/扎带 | 通用 | 若干 | 固定线束和软袋 | 自备或购买 | 用于应力释放

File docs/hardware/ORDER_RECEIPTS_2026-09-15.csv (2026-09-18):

状态 | 物品 | 规格 | 数量 | 金额 | 备注
已签收 | ESP32-S3开发板 | N16R8 向下焊 含Type-C数据线 | 1套 | 34.40
已签收 | ICM-20948 | MCU-20948 九轴模块 | 1个 | 48.94
已签收 | 面包板 | 400孔 MB102 | 1个 | 2.68
已签收 | 杜邦线 | 2.54mm 母对母 40P 20cm | 1排 | 4.20
已到货 | TP4057充电板 | TP4057-500mA Type-C | 2个 | 5.94 | 为避免选错规格购买
已到货 | TPS61088模块 | 固定5V版本 | 1个 | 11.32 | 焊盘版优先；到货后确认版本
已到货 | 高电流开关 | SS-12E07G4 1P2T 3A | 5只 | 4.89 | 首版主电源路径
已到货 | 备用低电流开关 | SS12D07VG4 1P2T 柄高4mm | 10只 | 2.40 | 不得用于升压输入主路径
已到货 | 电池 | 602535 3.7V 500mAh 带保护板 | 2个 | 18.76 | 先用后付待扣款
已到货 | PH2.0连接器 | 2P 公母一套 20cm | 2套 | 3.20
已到货 | PH2.0连接器 | 4P 公母一套 20cm | 5套 | 10.36
已到货 | 柔性线 | 26AWG 0.13平方 黑色2米 | 1根 | 3.50
已到货 | 柔性线 | 26AWG 0.13平方 红色2米 | 1根 | 3.50
已到货 | 热缩管 | 黑色200条 8种型号 | 1盒 | 7.80
已到货 | EVA泡棉 | 2mm厚 2.5cm宽 5米 | 1卷 | 4.80
已到货 | 传感器盒 | 5×3.5×1.8cm | 2个 | 2.28
已到货 | 主控收纳盒 | 10×7×2.3cm | 2个 | 3.18
已到货 | 元件盒 | 3#红色 | 1个 | 2.60
已到货 | 前臂绑带 | 5cm×50cm | 1条 | 5.00
已到货 | 腕部绑带 | 3.8cm×50cm | 1条 | 4.80
已到货 | 运动护腕 | 黑色1只+蓝色1只 | 2只 | 6.50 | 先用后付待扣款
已到货 | 电池软袋 | 布艺10×8cm | 1个 | 2.10

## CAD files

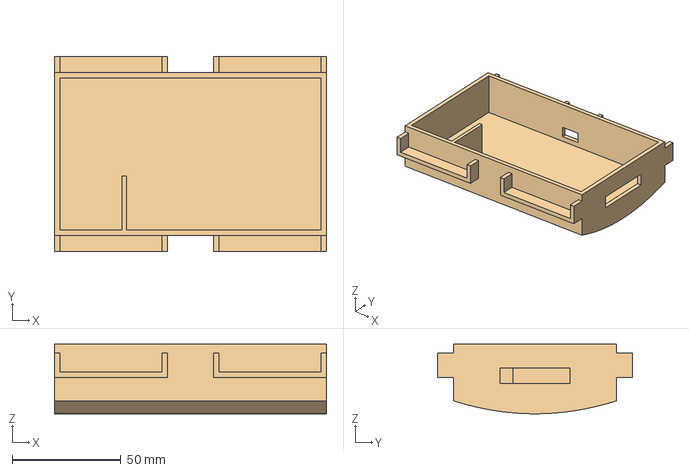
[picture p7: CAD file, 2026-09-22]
cad/node2_case/out/node2_open_top_v1.3mf
125.0 x 89.7 x 32.0 mm

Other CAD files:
cad/node2_case/out/node2_open_top_v1.stl

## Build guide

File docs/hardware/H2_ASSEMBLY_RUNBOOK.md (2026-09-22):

# H2 Assembly and Verification Runbook

基线：

```text
software_baseline_id = KB-2026-09-15-H1-F4-I1
software_commit      = ab44f2a
interface_revision   = I1
hardware_revision    = H2
H2 status            = assembling_and_verification
```

本文件是 2026-09-18 物料到齐后的执行顺序。软件接口以软件仓库的 I1 为准，硬件只负责装配、供电、机械固定和验证。

2026-09-19 软件联调同步的硬件检查项见 `docs/hardware/SOFTWARE_SYNC_2026-09-19.md`。

固定阶段执行清单见 `docs/hardware/FIXATION_RUNBOOK_2026-09-20.md`。

## 0. 首日开工检查

先不要接电池到整机，不要同时连接电脑 USB 和电池输出。

需要确认：

- [ ] 有数字万用表，通断档和 DC 电压档可用。
- [ ] 有电烙铁、焊锡、助焊剂、热缩管和剥线工具。
- [ ] 有纸胶带或标签，用来标记线序。
- [ ] 桌面绝缘，电池和裸露焊点不接触金属。
- [ ] 拍摄物料正面和接口丝印照片，照片不包含姓名、电话、地址。

## 1. 电池与 TP4057 断电检查

此阶段不接 ESP32，不接升压模块，不接负载。

### 1.1 电池电压

分别测量两块电池：

| 电池 | 预期 | 实测 |
|---|---:|---:|
| B1 | 3.0 到 4.2V | 3.88V |
| B2 | 3.0 到 4.2V | 3.92V |

注意电池红黑线和保护板极性，不要只看线色猜测极性。

### 1.2 TP4057 焊盘

先在断电状态下确认板上的丝印：

- 找到 `BAT+` 焊盘组。
- 找到 `BAT-` 焊盘组。
- 同极性焊盘内部应导通。
- `BAT+` 与 `BAT-` 之间不应导通。

检查：

- [x] 两个 `BAT+` 之间导通。
- [x] 两个 `BAT-` 之间导通。
- [x] `BAT+` 与 `BAT-` 不导通。
- [x] Type-C 口没有明显变形或短路。

确认日期：2026-09-18。B1、B2 电压和 TP4057 焊盘通断已由硬件端确认。

如果丝印和用户观察的左右两组关系不一致，先停下并拍照确认，不要焊。

## 2. 电池 PH2.0 2P 线束

目标线束：

```text
电池 B+  -> PH2.0 2P 一侧
电池 B-  -> PH2.0 2P 另一侧
```

要求：

- [x] 电池正极焊到 PH2.0 2P 一侧，负极焊到另一侧。
- [x] 焊接前先套热缩管，焊完后再收缩。
- [x] 焊接后逐根通断确认，不依赖线色。
- [x] 电池端和 TP4057 端使用匹配的公母头，避免正负极插反。
- [x] 焊点附近留 1 到 2cm 柔性缓冲，不让拉力直接落在焊盘上。

完成后的第一目标不是接 ESP32，而是独立充电测试。

## 3. TP4057 独立充电测试

接线只允许：

```text
电池 -> PH2.0 2P -> TP4057 BAT+ / BAT-
TP4057 Type-C <- 5V USB 充电器
```

此时：

- 不接 ESP32。
- 不接 TPS61088。
- 不接 SS-12E07G4 负载侧。
- 充电时保持观察，不要放在无人看管的封闭软袋中。

检查：

- [x] 充电红灯亮。
- [x] 电池电压缓慢上升，最终落在 4.15 到 4.20V 即可；不要求正好 4.20V。
- [x] TP4057 不出现明显烫手。
- [x] 电池不鼓包、不发烫、不异味。
- [x] 充电完成后绿灯亮。

2026-09-18 实测记录：

```text
B1 起始电压：                 3.89V
2.5 分钟：                    4.17V
5 分钟：                      4.17V
13.5 分钟：                   4.18V
15 分钟：                     4.18V
约 60 分钟：                  绿灯亮，4.16V
模块和电池温升：              无异常
```

充电电源为 10000mAh 充电宝，5V 输出。绿灯表示充电终止条件已满足；4.16V 属于可接受结果，后续以开路静置电压记录为准。

如果出现异常发热、异味、电压下降或保护板断开，立即断开 USB，停止测试。

## 4. ICM-20948 线束

固定接口：

```text
ICM VCC       -> ESP32 3V3
ICM GND       -> ESP32 GND
ICM SDI/SDA   -> ESP32 GPIO8
ICM SCLK/SCL  -> ESP32 GPIO9
ICM NCS       -> ESP32 3V3
ICM AD0       -> ESP32 GND

I2C address = 0x68
I2C clock   = 50kHz
WHO_AM_I    = 0xEA
```

4P PH2.0 线序固定：

```text
Pin 1 = VCC = 3V3
Pin 2 = GND = 公共地
Pin 3 = ICM SDI/SDA = GPIO8
Pin 4 = ICM SCLK/SCL = GPIO9
```

ICM 端就近处理：

```text
NCS -> 3V3
AD0 -> GND
```

检查：

- [ ] 4P 两端线序一致。
- [ ] VCC 对 GND 不短路。
- [ ] ICM SDI/SDA 对 GND 不短路。
- [ ] ICM SCLK/SCL 对 GND 不短路。
- [ ] NCS 与 3V3 导通。
- [ ] AD0 与 GND 导通。
- [ ] 传感器和主板共地。

先用电脑 USB 单独给 ESP32 供电，读取 `0x68` 和 `WHO_AM_I=0xEA`。此步通过前不要接电池供电链。

2026-09-19 ICM 4P 静态初始化记录：

```text
IMU_FLASH_V4_BOOT
FILESYSTEM_MOUNTING
FILESYSTEM_MOUNT_OK
FILESYSTEM,free=1433600,total=1441792
IMU_INIT,status=All is well.
IMU_CONFIG,acc=16g,gyro=2000dps,acc_dlpf=111.4Hz,gyr_dlpf=119.5Hz,odr_acc=225Hz,odr_gyr=220Hz,i2c=50000,addr=0x68
```

结论：ICM 4P 线束已通过初始化。`IMU_INIT,status=All is well.` 表示 SparkFun 库完成 `begin()` 和 `checkID()`，`WHO_AM_I` 已匹配 `0xEA`；I2C 使用 `0x68`、`50kHz`。此记录尚不等同于 10 秒静态采集通过。

## 5. 主电源链接线

当前首版主路径：

```text
500mAh 电池 B+ -> PH2.0 2P -> TP4057 BAT+
500mAh 电池 B- -> PH2.0 2P -> TP4057 BAT-

TP4057 另一组 BAT+ -> SS-12E07G4 3A 开关 -> TPS61088 IN+
TP4057 另一组 BAT- ------------------------> TPS61088 IN-

TPS61088 OUT+ 5V -> ESP32 5V
TPS61088 OUT-    -> ESP32 GND
```

如果 TP4057 的两组 BAT 焊盘都已经占用，不需要拆出新的 BAT 焊盘。直接把 `SS-12E07G4` 串到 TP4057 输出正极和 TPS61088 VIN+ 之间已有的红线上：

```text
TP4057 输出 BAT+ -- 红线 -- 开关中心脚
开关一个外侧脚 -- 红线 -- TPS61088 VIN+
TP4057 输出 BAT- --------- 黑线 --------- TPS61088 GND
```

开关只切正极，黑色地线保持直连。1P2T 开关只使用中心脚和一个外侧脚，另一个外侧脚空置；先按通断档确认两个使用脚在开关 ON 时导通、OFF 时断开。

当前首版不使用：

```text
P-MOS
AO3415
100k 电阻
1k 电阻
SS12D07VG4 作为主电流路径
```

规则：

- [ ] SS-12E07G4 接在电池正极路径，不切 3.3V。
- [x] TPS61088 出厂已配置为固定 5V；空载实测 5.01V，不再修改 5V、9V、12V、ADJ 或 PWM 焊盘。
- [ ] TPS61088 EN 不作为主断电开关。
- [ ] 不用 SS12D07VG4 承受升压输入主电流。
- [ ] 电脑 USB 与电池输出不能同时接 ESP32。
- [ ] USB 烧录或导出数据时，先关闭电池路径。
- [ ] TP4057 充电时关闭负载。

## 6. 升压和带载验证

### 6.1 空载

1. 电池接 TP4057。
2. 开关尚未接入时，可先把 TP4057 空闲 BAT+ / BAT- 临时接到 TPS61088 VIN / GND。
3. 不修改 TPS61088 的 5V、9V、12V、ADJ、PWM 焊盘。
4. 不接 ESP32，不接任何输出负载。
5. 万用表测 TPS61088 VOUT 对 GND。

验收：

- [x] 空载输出约 5.00V。
- [x] 输出没有明显周期性跌落。
- [x] 模块不出现明显发热。

2026-09-18 实测记录：

```text
输入电池电压：                4.15V
TPS61088 VOUT 对 GND：        5.01V
5V 跳线是否手工短接：         否，出厂固定 5V 配置已生效
ESP32 是否接入：              否
输出负载：                    无
模块温升：                    无异常
```

结论：TPS61088 固定 5V 空载测试通过。左边圆形焊点和红框跳线都不要动。

2026-09-19 开关串联实测记录：

```text
电池两端电压：                4.12V
开关 OFF：TPS61088 VIN/GND     0V
开关 ON：TPS61088 VIN/GND      4.12V
开关 ON：TPS61088 VOUT/GND     5.02V
```

结论：SS-12E07G4 已正确串入电池正极路径；开关 OFF 能切断升压输入，ON 后升压输出保持约 5V。

2026-09-19 电池、开关和 ESP32 供电链路复测记录：

```text
电池两端：                       4.10V
开关 OFF：TPS61088 VIN/GND       0.13V
开关 OFF：TPS61088 VOUT/GND      0.01V
开关 ON： TPS61088 VIN/GND       4.07V
开关 ON： TPS61088 VOUT/GND      5.02V
连续开关循环：                   20 次，无异常
蓝灯恢复：                       每次正常
ESP32 复位：                     无异常
电池保护板跳闸：                 无
```

判定：OFF 时约 0.13V 输入残压属于输入电容和漏电范围，VOUT 已降到 0.01V，升压和 ESP32 均能正常断电。ON 时开关压降约 0.03V，升压输出 5.02V，20 次开关循环通过。

2026-09-19 电池供电冷启动和完整电压链记录：

```text
电池两端：                       4.08V
TPS61088 VIN / GND：             4.06V
TPS61088 VOUT / GND：            5.02V
ESP32 5V / GND：                 5.02V
ICM VCC / GND：                  3.26V
电池冷启动：                     5/5 通过
OFF 后蓝灯熄灭：                 正常
ON 后蓝灯恢复：                  正常
额外 RST 需求：                  无
反复复位：                       无
电池保护板跳闸：                 无
开关、升压、电池温升：           无异常
电池供电采集：                   3 次静止 + 2 次小幅举臂已完成并导出
```

说明：硬件链路和冷启动门槛已通过。软件端已于 2026-09-19 完成 3 次电池供电静止采集和 2 次小幅举臂采集验收，5 份数据均通过。当前电池供电链可进入机械假装配阶段。

### 6.2 ESP32 启动

1. 关闭开关。
2. 将 TPS61088 OUT+ 接 ESP32 5V，OUT- 接 ESP32 GND。
3. 打开开关。
4. 确认 GPIO48 RGB 蓝色常亮，只有蓝灯不亮时才按一次 RST。
5. 进入 10 秒记录流程并观察电压。

验收：

- [ ] 启动和记录期间输出不低于约 4.85V。
- [ ] 无反复复位。
- [ ] 无蓝灯熄灭后自动恢复的掉电现象。
- [ ] SS-12E07G4 两端没有明显烫手或可见压降异常。
- [ ] 连续开关 20 次无复位、无电池保护板跳闸。

如果 4.85V 门槛不过，先停止真实投篮准备，记录最低电压和发生时刻。

## 7. 机械装配

### 7.1 腕部传感器单元

- [ ] ICM 放入 `5 × 3.5 × 1.8cm` 传感器盒。
- [ ] 盒底加 2mm EVA。
- [ ] 盒子固定在腕横纹向手肘方向 2 到 4cm。
- [ ] 盒子箭头每次朝向手肘。
- [ ] 线束入口先固定，再进入盒子。

### 7.2 前臂单元

- [ ] ESP32、TP4057、开关、TPS61088 和电池先单层摆放在 `10 × 8cm` 软袋中。
- [ ] 电池靠近手肘，模块靠近手腕侧，避免重量集中在腕部。
- [ ] 模块之间加 EVA 或薄泡棉。
- [ ] 用 5cm 前臂绑带固定，避开肘窝。
- [ ] USB-C 口保持可访问。

## 8. 最终测试门槛

真实投篮前必须全部通过：

- [ ] 10 秒静止测试。
- [ ] 小幅动态测试。
- [ ] 无复位。
- [ ] 无全零。
- [ ] 无固定饱和。
- [ ] 无削顶。
- [ ] 最大采样间隔不超过 10ms。
- [ ] 采样率在 `210-240Hz`，或中位采样间隔在 `4.0-4.8ms`。
- [ ] 快速屈伸腕部和摆臂时，插头和焊点没有位移。

## 9. 需要回报的数据

每完成一个阶段，把以下内容回报给硬件对话：

```text
阶段名称：
是否通过：
万用表读数：
是否发热：
是否复位：
照片文件名：
发现的问题：
下一步：
```

不要把订单页面、姓名、电话或地址照片上传到仓库。

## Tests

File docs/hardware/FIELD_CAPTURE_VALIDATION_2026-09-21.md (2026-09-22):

# Field Capture Validation - 2026-09-21

## Result

The wearable H2 hardware completed a same-player court shooting session on 2026-09-21.

```text
session: session_20260921_185918
captures exported: 13
capture_001: excluded as invalid by the operator
accepted captures: 12
```

The 12 accepted captures passed file-level row-count, timing-gap, sequence, and
saturation checks in the software workflow.

## Current Capture Contract

```text
F4 record duration: 15 seconds
sample rate: approximately 226.9Hz
expected rows: approximately 3403-3404
empty/partial file: rejected
acceleration saturation: none in accepted files
gyroscope saturation: none in accepted files
```

## Hardware State

```text
wrist sensor enclosure: fixed
forearm box and module fixation: fixed for field use
four-wire ICM interface: preserved
ICM address: 0x68
WHO_AM_I: 0xEA
battery + TP4057 + SS-12E07G4 + TPS61088 + ESP32: validated
```

LED transitions were used for the initial video/IMU synchronization workflow.
The initial phase alignment is software-side evidence and remains open for
release-frame and shot-outcome mapping.

## Next Hardware Step

Wait for the upper-arm IMU accessory, then prepare Node 2:

```text
upper-arm enclosure
independent protected battery B2
independent TP4057, switch, TPS61088, and ESP32 path
keep Node 1 and Node 2 power and ground independent unless software defines a synchronization connection
verify each node separately before dual-node capture
```

Do not claim synchronized joint angles, ball release speed, or complete dual-node
validation until Node 2 is assembled and validated.

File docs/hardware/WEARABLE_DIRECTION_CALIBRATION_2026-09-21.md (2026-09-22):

# Wearable Direction Calibration - 2026-09-21

## Hardware State

The sensor enclosure and wrist fixation are now stable enough for direction
calibration:

```text
wrist position: approximately 4 cm from wrist toward elbow
body +Y: toward the hand
body +Z: toward the back of the hand
body +X: ulnar direction
```

The enclosure is wider at the base and narrower at the top. This shape must be
retained in the mechanical documentation because it introduces known
face-alignment errors during desktop calibration.

## Confirmed Sensor Mounting

```text
body +X -> sensor -Y
body +Y -> sensor -Z
body +Z -> sensor +X
```

The mapping was independently confirmed by:

```text
wearable wrist rotations
desktop face-down tests
controlled rotations around body X, Y, and Z
```

## Desktop Calibration Data

Session: `session_20260921_015500`

The first capture was discarded by the operator. The remaining nine captures
passed timestamp continuity and saturation checks. The measured residual tilt
includes both the table tilt of approximately 2 degrees toward 324-326 degrees
and the enclosure-face angle.

## Mechanical Rules

- Do not rotate or remount the IMU relative to the wrist strap.
- Keep the cable strain relief away from the sensor enclosure.
- Mark the +Y hand direction and +Z back-of-hand direction on the enclosure.
- Keep the enclosure orientation identical between sessions.
- Record any strap or enclosure change as a new calibration event.

## Next Validation

At the court:

```text
hold the starting posture for 2 seconds
record several static and shooting captures
keep body heading unchanged within one comparison group
record body heading separately when court direction matters
```

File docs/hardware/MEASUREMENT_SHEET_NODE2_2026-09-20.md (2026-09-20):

# Node 2 3D Enclosure Measurement Sheet - 2026-09-20

Target: upper-arm node enclosure for the second independent IMU node.

Use millimeters. Measure actual installed parts where possible. If a solder joint, connector, or wire bend increases the envelope, include it in the measured value.

## 1. Upper-Arm Geometry

Record the intended arm and orientation:

```text
left or right arm:
case center distance from elbow: ____ mm
case long-axis direction: parallel to humerus
outer/lateral side position:
preferred case length: ____ mm
preferred case width around arm: ____ mm
preferred maximum thickness: ____ mm
upper-arm circumference at case center: ____ mm
upper-arm circumference at center - 30mm: ____ mm
upper-arm circumference at center + 30mm: ____ mm
```

If possible, make a simple paper/cardboard mock shell and record whether the curved inner surface follows the arm without bridging or pinching.

## 2. ESP32-S3 Module

```text
PCB length: ____ mm
PCB width: ____ mm
PCB thickness: ____ mm
maximum height including header pins: ____ mm
maximum height including USB-C shell: ____ mm
overall envelope length including USB-C: ____ mm
overall envelope width: ____ mm
overall envelope thickness: ____ mm
COM USB-C center from nearest end: ____ mm
COM USB-C center from nearest side: ____ mm
USB-OTG USB-C center from nearest end: ____ mm
BOOT button center from nearest end/side: ____ mm
RST button center from nearest end/side: ____ mm
GPIO48 RGB center from nearest end/side: ____ mm
antenna keep-out area: ____ mm x ____ mm
preferred face toward lid:
```

Important:

- identify the `COM` USB-C port used for flashing/export
- keep the antenna area clear of battery, metal, and dense wiring
- keep BOOT, RST, and RGB accessible

## 3. ICM-20948 Module

```text
length: ____ mm
width: ____ mm
PCB thickness: ____ mm
height with soldered header/pins: ____ mm
height with 4P connector mated: ____ mm
4P cable exit direction in final assembly:
mounting-hole spacing:
clearance needed around NCS/AD0 jumpers: ____ mm
clearance needed around 4P latch: ____ mm
```

The ICM should have its own low-profile pocket or foam-isolated sub-shell.

## 4. TPS61088 Boost Module

```text
PCB length: ____ mm
PCB width: ____ mm
PCB thickness: ____ mm
maximum height including inductor: ____ mm
terminal type: solder pad / KF301 / other
maximum height including terminals: ____ mm
VIN pad location from board corner: ____ mm / ____ mm
VOUT pad location from board corner: ____ mm / ____ mm
GND pad locations from board corner: ____ mm / ____ mm
input/output wire bend envelope: ____ mm
```

Keep ventilation space around the boost module.

## 5. TP4057 Charging Module

```text
PCB length: ____ mm
PCB width: ____ mm
PCB thickness: ____ mm
height including Type-C shell: ____ mm
Type-C opening dimensions: ____ mm x ____ mm
Type-C center from nearest corner: ____ mm / ____ mm
BAT pad group positions: ____ mm
required service access for charging: open lid / side opening
```

## 6. SS-12E07G4 Switch

```text
body length: ____ mm
body width: ____ mm
body height without handle: ____ mm
handle extra height: ____ mm
pin spacing: ____ mm
required handle travel: ____ mm
desired handle access: lid slot / side slot
```

## 7. Battery B2

```text
length including protection board: ____ mm
width including protection board: ____ mm
thickness including protection board: ____ mm
wire exit side:
wire length available: ____ mm
connector envelope: ____ mm
preferred battery position in case: shoulder/proximal end
```

The battery must not be compressed, folded, or placed directly over the ESP32 antenna.

## 8. Connectors and Wiring Volume

```text
wire gauge:
number of power wires:
number of 4P signal wires:
maximum bundle diameter: ____ mm
preferred minimum bend radius: ____ mm
estimated folded wire volume: ____ mm^3
number of service loops:
service-loop length at ICM: ____ mm
service-loop length at ESP32: ____ mm
```

Sketch or photograph the proposed wire path before measuring the bundle.

## 9. Enclosure Features

- [ ] curved arm-facing surface
- [ ] separate ICM pocket
- [ ] battery pocket
- [ ] boost-module ventilation
- [ ] ESP32 COM USB-C opening
- [ ] BOOT opening
- [ ] RST opening
- [ ] RGB visibility window
- [ ] switch access slot
- [ ] 4P cable exit with strain relief
- [ ] removable lid with M2.5 heat-set inserts
- [ ] antenna plastic-only zone
- [ ] two arm-band slots or attachment points

## 10. Print and Assembly Constraints

```text
printer build volume: ____ x ____ x ____ mm
preferred material: PETG / ASA / PA12 / other
nozzle diameter: ____ mm
layer height: ____ mm
available screw/insert size:
printer or print service:
tolerance preference:
```

## 11. Photos to Provide

- ICM module top and bottom with ruler
- ESP32 top, bottom, USB-C end, and button end with ruler
- TPS61088 top, bottom, input/output ends with ruler
- TP4057 top and bottom with ruler
- switch side and pin view with ruler
- battery with protection-board side and wire exit with ruler
- proposed wire path or paper mock shell on the upper arm

## 12. CAD Deliverables After Measurements

The hardware conversation can produce:

```text
parametric enclosure model
preview images
STL / 3MF print files
STEP file when a CAD export is available
opening-position diagram
assembly and service-access diagram
```

The design will remain mechanical-only. Firmware, I2C address, NCS/AD0, data format, and multi-node synchronization stay outside this document.

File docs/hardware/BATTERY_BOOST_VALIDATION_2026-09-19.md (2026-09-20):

# Battery and Boost Validation - 2026-09-19

## Result

The battery and boost power path completed five consecutive valid captures:

```text
3 static
2 small arm raises
```

All files contain approximately 2269-2270 rows at approximately 226.9 Hz with
no gaps of 20 ms or more, no empty file, no partial file, and no saturation.

Validated chain:

```text
protected 3.7 V battery
-> TP4057 BAT+ / BAT-
-> SS-12E07G4 3 A main switch
-> TPS61088 fixed 5 V boost
-> ESP32 5V and GND
```

## Hardware Interpretation

The electrical power chain is functional. The next task is mechanical:

- anchor the battery and boost assembly in the forearm pouch
- add strain relief to the battery, USB, ESP32, and ICM cables
- keep the ESP32 and sensor cable from carrying battery weight
- keep USB-C, BOOT, and RGB LED accessible
- verify no exposed solder joint can contact the battery or shield

## Validation After Fixation

Repeat:

```text
3 static captures
2 small arm-raise captures
```

The fixation passes only when all five captures retain the same row count,
sample rate, gap, saturation, and non-empty-file criteria.

## Safety Rules

- TP4057 has no load sharing. Turn the ESP32 load off while charging.
- Never connect USB 5 V and battery-boost 5 V simultaneously.
- Keep SS12D07VG4 out of the main boost input path.
- Keep TPS61088 EN separate from the main power switch.

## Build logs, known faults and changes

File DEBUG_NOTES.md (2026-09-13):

# 初版调试记录

日期：2026-09-13

## 一、目标

先完成单节点硬件验证：

```text
ESP32-S3 + ICM-20948 + USB 供电
```

验证内容包括：

- ESP32-S3 能被电脑识别和烧录
- ICM-20948 能通过 I2C 扫描到
- 能读取加速度、角速度、磁力计和温度
- 能连续保存 CSV
- 能生成第一版运动曲线

## 二、硬件连接

### 直接接线

最初验证的接法：

```text
ESP32-S3 3V3   -> ICM-20948 VCC
ESP32-S3 GND   -> ICM-20948 GND
ESP32-S3 GPIO8 -> ICM-20948 SDA
ESP32-S3 GPIO9 -> ICM-20948 SCL
```

### 面包板接线排号

调试过程中记录的排号：

```text
ESP32 3V3   = 第 42 排
ESP32 GND   = 第 64 排
ESP32 GPIO8 = 第 53 排
ESP32 GPIO9 = 第 56 排
```

```text
ICM VCC = 第 28 排
ICM GND = 第 29 排
ICM SCL = 第 30 排
ICM SDA = 第 31 排
```

注意：面包板中间断槽两边的孔不连通，插线必须和端口所在半边一致。

## 三、遇到的问题

### 问题 1：ESP32 开发板包下载失败

现象：

```text
Failed to install platform esp32:3.3.11
Connection failed
```

原因：

- Arduino IDE 从 GitHub 下载 ESP32 工具链时网络连接失败。

解决思路：

- 获取 Espressif Arduino 包索引。
- 将 GitHub 下载地址改写为乐鑫中国镜像。
- 启动本机索引服务，供 Arduino IDE 使用。
- 使用 Arduino IDE 内置的 arduino-cli 安装 ESP32 核心。

结果：

```text
esp32:esp32 3.3.11 installed
```

### 问题 2：ICM-20948 没有预焊排针

现象：

- 购买的 ICM-20948 模块排针未焊。

处理：

- 焊接 2.54mm 单排针。
- 排针保持垂直，不能倾斜。
- 使用面包板固定排针后再焊接。

结果：

- 排针焊好后模块可以插入面包板并使用杜邦线连接。

### 问题 3：I2C 扫描不到设备

现象：

```text
I2C scanner started
```

没有稳定的 `0x68` 或 `0x69`。

可能原因：

- SDA/SCL 接反。
- 排线插错面包板半边。
- VCC 或 GND 没有真正连通。
- 杜邦线或排针接触不良。
- AD0 引脚状态不稳定。

处理过程：

- 检查 `SDA`、`SCL`、`VCC`、`GND`。
- 对调 SDA/SCL 做软件和接线测试。
- 发现 `0x0C`、`0x68`、`0x69` 交替出现。
- 最终稳定使用地址 `0x69`。

结果：

```text
Found device at 0x69
```

### 问题 4：出现 Data Underflow

现象：

```text
Trying AD0_VAL=0 status=Data Underflow
Trying AD0_VAL=1 status=Data Underflow
```

分析：

- I2C 地址有响应，但寄存器读取数据不完整。
- 采集程序设置了 `Wire.setClock(400000)`，而扫描程序使用默认的约 `100kHz`。
- 面包板和杜邦线在 400kHz 下容易出现时序和接触问题。

处理：

- 将 I2C 时钟改为 `100000`。

结果：

- 采集固件已更新为 100kHz，待明天继续验证。

### 问题 5：采集过程中数据停止或饱和

现象：

- 第一次采集保存 36 行。
- 第二次采集保存 201 行，采样率约 45Hz。
- 第三次采集保存 842 行，持续 30 秒，采样率约 28Hz。
- 第三次数据最后约 5.5 秒出现固定饱和值：

```text
GX = -500.27 dps
GY = 500.26 dps
AZ = 3999.88 mg
```

分析：

- 饱和值不是正常动作数据，可能是接线松动或 I2C 通信异常。
- 杜邦线、面包板接触和 USB 线拉扯会影响数据连续性。

处理：

- 固定主板、传感器、USB 线和四根信号线。
- 移动时移动整块底板，不单独拉扯传感器。
- 固件增加错误判断，通信异常时不再写入无效数据。

结果：

- 短时间数据有效。
- 长时连续采集仍需要继续验证接线稳定性。

## 四、当前结果

已完成：

- ESP32-S3 正常烧录和串口输出
- ICM-20948 排针焊接
- I2C 地址扫描
- 获得 `0x69` 地址
- 真实加速度、角速度、磁力计和温度数据读取
- 201 行和 842 行两段采样数据
- 生成运动曲线图

尚未完成：

- 长时稳定采集
- 面包板接线完全稳定
- 正式投篮动作数据采集

## 五、下一步

1. 上传最新的 100kHz 自动地址检测固件。
2. 串口确认出现：

```text
IMU_READY
```

3. 固定传感器和线束后重新采集 30 秒。
4. 确认保存行数大于 800。
5. 确认温度正常，没有长时间固定饱和值。
6. 稳定后再进行第一次实际投篮动作采集。

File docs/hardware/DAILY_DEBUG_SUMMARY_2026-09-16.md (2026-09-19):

# 2026-09-16 硬件难点、采购与装配调试总记录

基线：

```text
software_baseline_id = KB-2026-09-15-H1-F4-I1
software_repository  = koreever66/kineshoot-initial-debug-v2
software_branch      = codex/software-data
software_commit      = 3162aa345627cc501781a91dbd21d02cdae4fe0a
interface_revision   = I1
hardware_revision    = H2
hardware_branch      = codex/hardware-bringup
```

当前硬件状态必须保持：

```text
H2 status = assembling_and_verification
```

H2 尚未完成实物装配、照片、万用表检查和静止/动态测试，不能标记为完成。

本文件汇总本轮硬件对话中遇到的主要问题、决策、未解决风险和配件到货后的装配调试路径。订单截图中的姓名、电话、地址和快递信息没有上传。

## 0. 关键背景：为什么一开始没有采购升压模块

最初 H1 硬件基线的供电方式是：

```text
充电宝 5V -> 电源开关 -> ESP32 5V
```

因为充电宝已经输出 5V，所以早期采购清单不需要 `3.7V -> 5V` 升压模块。最初的物料重点只是面包板、杜邦线、ESP32、ICM 和基础采集。

后来硬件方案从 H1 台架测试向 H2 可穿戴设备推进，开始采用：

```text
3.7V 锂电池 -> TP4057 -> 电源开关 -> ESP32
```

这个硬件供电树存在一个被漏掉的接口：

```text
TP4057 输出只有约 3.0 到 4.2V
ESP32 开发板 5V 引脚需要稳定 5V
```

今天下午与软件端同步接口、统一基线和检查完整供电链时，才发现早期采购中没有包含升压模块。这个问题不是软件采样、地址或数据格式问题，而是硬件供电架构从“充电宝 5V”切换到“锂电池可穿戴”后，采购 BOM 没有同步更新导致的遗漏。

最终修正方案：

```text
500mAh 电池 -> TP4057 -> SS-12E07G4 3A开关 -> TPS61088 固定5V -> ESP32 5V
```

同时不再需要 P-MOS、AO3415、100k 和 1k 电阻。

记录这条时间线的原因：

- 采购必须以冻结后的完整供电树为基准。
- 软件接口、硬件接口和电源接口必须在采购前同步。
- 不能只根据早期 H1 的充电宝方案推导 H2 可穿戴物料。
- 后续任何供电路径变化都必须重新检查 BOM。

软件测试供电边界补充：

```text
软件当前测试：电脑 USB 或充电宝 5V 直接给 ESP32
H2 集成测试：电池 -> TP4057 -> 3A开关 -> TPS61088 -> ESP32
```

因此 P-MOS 与直接 3A 开关的选择属于 H2 硬件实现，不影响当前软件接口测试。软件测试只需要 ESP32 5V、BOOT/RST、GPIO48 RGB 和 USB CDC 行为符合基线。

## 1. 今天已经完成的工作

- 确定了硬件仓库和软件仓库的分工边界。
- 锁定软件基线 `KB-2026-09-15-H1-F4-I1`，接口版本 `I1`，硬件版本 `H2`。
- 固定 ICM-20948 通信接口。
- 确认现有 PH2.0 4P 可以继续使用，不需要 6P。
- 完成今日采购统计，有效订单 22 项，总成本约 ¥193.15。
- 确认 TPS61088 固定 5V 模块方案。
- 不将不可靠的低压成品 P-MOS 模块作为主方案。
- 改用 SS-12E07G4 3A 开关直接控制电池正极主路径。
- 确认电池保护板为 1C 持续、2C 峰值、1C 最大充电。
- 完成 ESP32、ICM、TP4057、TPS61088 和穿戴尺寸的初步核算。
- 将硬件资料、订单 BOM、尺寸和测试方案同步到硬件仓库。
- 同步软件提交 `3162aa345627cc501781a91dbd21d02cdae4fe0a`。
- 记录 GPIO48 RGB 状态灯、时间戳导出目录和新增元数据字段。

## 1.1 软件端同步修正清单

| 级别 | 问题 | 硬件端处理 | 状态 |
|---|---|---|---|
| P0 | H2 不能提前标记完成 | 所有当前文档统一标记为 `assembling_and_verification`，完成项必须等实测和照片 | 已修正 |
| P1 | 开关路径描述矛盾 | 明确开关位于升压前的 3.7-4.2V 电池正极路径，不在 5V 路径 | 已修正 |
| P1 | SS12D07VG4 电流额定不足风险 | 明确常见额定约 0.5A，数据手册确认 1A 前不得用于主路径；主路径改用 SS-12E07G4 3A | 已修正 |
| P1 | TP4057 无负载共享 | 明确充电时必须关闭负载，USB 烧录或导出时必须断开电池输出，避免双 5V 倒灌 | 已修正 |
| P1 | SDA/SCL 与模块印字不一致 | 统一为 `ICM SDI/SDA` 和 `ICM SCLK/SCL` | 已修正 |
| P2 | 采样率验收过窄 | 硬件验收改为 `210-240Hz` 或中位采样间隔 `4.0-4.8ms` | 已修正 |
| P2 | 旧固件目录误用风险 | 根目录旧内容已迁入 `legacy/firmware-v1`、`legacy/tools-v1`、`legacy/data-v1`、`legacy/plots-v1` | 已修正 |

## 2. 固定接口和不可修改项

```text
ICM VCC  -> ESP32 3V3
ICM GND  -> ESP32 GND
ICM SDI/SDA  -> ESP32 GPIO8
ICM SCLK/SCL -> ESP32 GPIO9
ICM NCS  -> ESP32 3V3
ICM AD0  -> ESP32 GND

I2C address = 0x68
I2C clock   = 50kHz
WHO_AM_I    = 0xEA
```

硬件不得静默修改：

- 引脚定义。
- PH2.0 4P 线序。
- `NCS` 和 `AD0` 固定电平。
- 地址、I2C 时钟和数据格式。
- 3.3V 电源路径。
- 软件 F4 的记录时长、量程、触发方式和采样逻辑。

## 3. 今天遇到的难点

### 3.1 旧调试基线与新软件基线冲突

问题：

- 旧记录中存在 `0x69`、`0x0C`、`100kHz` 和 `0x68/0x69` 自动探测。
- 新软件基线要求固定 `0x68`、`50kHz` 和 `WHO_AM_I=0xEA`。

影响：

- 如果继续沿用旧固件和旧地址，硬件测试结果不能作为当前 F4 基线证据。

解决：

- 将所有硬件当前文档更新为新基线。
- 旧内容保留为历史记录，不再作为当前目标。
- 禁止用 `0x69` 或 `0x0C` 作为长期主地址。

状态：已解决，待实物复测。

### 3.2 NCS 和 AD0 的连接方式

问题：

- 如果 NCS 或 AD0 悬空，通信可能不稳定。
- 增加这两根线后，是否必须换成 6P 连接器。

解决：

- `NCS -> 3V3`、`AD0 -> GND`，在 ICM 端就近固定。
- 固定电平后只保留 VCC、GND、ICM SDI/SDA、ICM SCLK/SCL 四根线。
- 现有 PH2.0 4P 足够，不需要采购 6P。

状态：方案已确定，待焊后万用表验证。

### 3.3 面包板和杜邦线接触不稳定

问题：

- 面包板阶段的 I2C 曾出现通信异常、固定饱和和异常值。
- 投篮动作振动会让排针、面包板和杜邦线接触变化。

影响：

- 数据质量不可信，可能误判为传感器或算法问题。

解决：

- 改用 26AWG 柔性线和 PH2.0 连接器。
- 焊接焊点并做应力释放。
- 连续扫描至少 5 分钟，再做 10 秒记录和动态测试。

状态：待配件到货后执行。

### 3.4 充电模块选型

问题：

- 常见 TP4056 模块充电电流为 1A。
- 500mAh 电池用 1A 充电约为 2C，偏大。

解决：

- 选择 TP4057-500mA 版本。
- 电池最大充电倍率为 1C，即 500mA，和 TP4057-500mA 匹配。
- 实际订单购买 2 个 TP4057 模块。

状态：已采购，待充电测试。

### 3.5 升压模块选型

问题：

- H1 原方案由充电宝直接提供 5V，采购时没有升压模块。
- 切换到 H2 电池可穿戴后，TP4057 输出只有电池电压，不能直接接 ESP32 5V。
- TP4057 输出是电池电压，不能直接给 ESP32 的 5V 引脚。
- 便宜的 3.7V 转 5V 模块有些只有电位器，可能有电压漂移。

解决：

- 下午与软件端同步完整供电链接口时确认了这个缺口。
- 追加采购 TPS61088 固定 5V 版本。
- 选择 TPS61088 固定 5V 版本。
- 使用 5V 跳线锁定，不使用电位器长期调压。
- 输入范围 `2.7-12V`，覆盖电池 `3.0-4.2V`。
- 3V 输入、5V 输出时表格标称最大输出约 `3.78A`。

状态：已采购，待空载和带载测试。

### 3.6 TPS61088 焊盘版和端子版差异

问题：

- 商品链接包含焊盘版和 KF301 螺丝端子版。
- 端子版约 10g，焊盘版约 5.4g。
- 端子版更厚，约增加 4 到 5mm。

解决：

- 穿戴设备优先焊盘版。
- 端子版只用于台架测试或临时方案。
- 到货后先确认版本，再决定是否焊接。

状态：订单为固定 5V 版本，焊盘/端子版仍待收货确认。

### 3.7 TPS61088 EN 不等于主电源开关

问题：

- EN 接 GND 只是关闭升压，不是完全断开输出。
- 关机状态下输出可能仍接近或略低于输入。

解决：

- EN 不作为主电源开关。
- 主开关放在电池正极路径。
- TPS61088 负责升压，不负责彻底断电。
- TP4057 不具备负载共享；充电时必须关闭负载，USB 烧录或导出时必须断开电池输出，避免双 5V 倒灌。

状态：已明确。

### 3.8 低电流开关不适合主路径

问题：

- 最初购买的 SS12D07VG4 额定电流约 0.5A。
- 升压输入峰值可能接近或超过 1A，不适合串联承载主电流。
- SS12D07VG4 的额定值仍必须以数据手册为准；在确认达到 1A 前，不得用于升压输入主路径。

解决：

- 放弃 SS12D07VG4 主路径。
- 采购 SS-12E07G4，1P2T，3A，5 只装。
- SS12D07VG4 仅作为备用或低电流控制。

状态：已采购，待装配验证。

### 3.9 成品 P-MOS 高边模块难以找到

问题：

- 许多所谓 MOS 模块是 N-MOS 低边，会切断公共地。
- F5305S 类模块标称受控输出 `5-36V`，不适合 `3.0-4.2V` 电池路径。
- 带 EN/CTRL 且明确支持 3.0V 的成品模块很难确认。

解决：

- 主方案改为 SS-12E07G4 3A 开关直接控制电池正极。
- 当前主方案不需要 P-MOS、100k、1k 或 AO3415。
- P-MOSFET + SS12D07VG4 作为回退方案保留，只有 SS-12E07G4 不适用时才启用。
- SS12D07VG4 不单独用于升压输入主电流路径。

状态：主方案已改为 3A 直接开关。

### 3.10 电池放电能力限制

问题：

- 商品页先显示放电倍率 `0.5C`。
- `0.5C × 500mAh = 250mA`，连续放电能力偏紧。
- 后续客服确认保护板为 `1C` 持续、`2C` 峰值。

最终参数：

```text
持续放电：1C = 500mA
峰值放电：2C = 1000mA
最大充电：1C = 500mA
过流保护点：商家不知道
```

影响：

- TPS61088 标称 2A，不能理解为电池可以持续提供 2A。
- ESP32 实际平均负载必须低于 500mA 电池输入。
- 启动瞬间电容充电峰值不能长期接近或超过 1A。

状态：电池可用，待实测启动和平均电流。

### 3.11 尺寸和穿戴包络

问题：

- ESP32 商家尺寸不含排针高度。
- 含 Type-C 总长约 `63.611mm`，不能装进 7 × 5cm 小袋。
- ICM 模块实际只有 `15.32 × 26.54mm`，当前 50 × 35 × 18mm 盒子偏大。
- 前臂软袋 100 × 80mm 对开发板版本是必要的，但偏大。

解决：

- 布局按 ESP32 `64 × 28mm` 预留。
- 前臂软袋第一版使用 10 × 8cm。
- 传感器盒第一版可用，最终目标缩小到约 35 × 22 × 10mm。
- 排针高度等焊好后实测。

状态：第一版可以装配，最终小型化需要定制 PCB。

### 3.12 GitHub 网络连接和提交同步

问题：

- `github.com:443` 多次连接重置或超时。
- Git fetch/push 间歇性失败。

解决：

- 使用 GitHub API 作为备用同步通道。
- 按固定 blob、tree 和 commit 校验上传。
- 分支保持 `codex/hardware-bringup`，没有合并到 `main`。

状态：硬件文档已同步。

### 3.13 个人隐私

问题：

- 多张订单截图包含姓名、手机号和地址。

解决：

- 不把原始截图上传 GitHub。
- 仓库只记录商品、规格、数量和价格。

状态：已执行。

## 4. 当前采购状态

已签收：

- ESP32-S3-N16R8
- ICM-20948
- 400 孔面包板
- 40P 母对母杜邦线

待收货：

- TP4057-500mA
- TPS61088 固定 5V
- SS-12E07G4 3A 开关
- SS12D07VG4 备用开关
- 602535 电池
- PH2.0 2P 和 4P
- 26AWG 红黑柔性线
- 热缩管
- EVA 泡棉
- 传感器盒和主控收纳盒
- 前臂和腕部绑带
- 前臂软袋

仍然缺或待确认：

- 万用表通断档。
- 魔术贴、纸胶带、扎带或医用胶带。
- 电池过流保护点。
- TPS61088 焊盘版或端子版。

## 5. 配件到货后的装配顺序

### 阶段 0：开箱和验收

- 核对订单数量。
- 检查 PH2.0 是 2.0mm，不是 1.25mm 或 2.54mm。
- 检查电池是否鼓包、破损。
- 检查 TPS61088 是焊盘版还是端子版。
- 测量 TP4057、TPS61088、电池和开关的实际尺寸。

### 阶段 1：电池和 TP4057

- 自己焊接 PH2.0 2P 到电池线。
- 用万用表确认正负极。
- 先不接 ESP32，单独充电。
- 观察红灯充电、绿灯或红灯熄灭状态。
- 充完测量电池电压，应接近 4.2V。

### 阶段 2：开关和 TPS61088

- 将 SS-12E07G4 串到 TP4057 输出正极和 TPS61088 VIN+ 之间。
- TPS61088 只短接 `5V` 跳线。
- 不接 ESP32，空载测输出，目标约 5.00V。
- 接 ESP32，测启动和记录时是否低于 4.85V。
- 如果模块有 EN，保持 EN 为开启状态，不把 EN 当主开关。

### 阶段 3：ICM 柔性线束

- 焊接 ICM VCC/GND/SDI-SDA/SCLK-SCL。
- ICM 模块实际印字为 SDI/SCLK，文档统一写作 `SDI/SDA` 和 `SCLK/SCL`。
- NCS 就近接 3V3，AD0 就近接 GND。
- 焊到 PH2.0 4P，线长控制在 10 到 15cm。
- 用万用表逐根检查，不允许短路或接错。
- 上电前确认 ESP32 只通过 USB 供电。
- 运行 I2C 扫描，确认 `0x68` 和 `WHO_AM_I=0xEA`。

### 阶段 4：机械装配

- ICM 放入 5 × 3.5 × 1.8cm 小盒，盒底贴 EVA。
- 盒子贴到 3.8cm 腕带，位置在腕横纹上方 2 到 4cm。
- ESP32、TP4057、TPS61088、开关和电池单层放进 10 × 8cm 软袋。
- 用 5cm 前臂带固定，位置在腕横纹上方 5 到 10cm。
- 每个线束两端留缓冲弯，用胶带或扎带固定。

### 阶段 5：上电和静态测试

- 用万用表检查 VCC/GND、SDA/GND、SCL/GND 是否短路。
- 测量 ICM VCC 约 3.3V。
- 测量 NCS 约 3.3V。
- 测量 AD0 约 0V。
- 测量 TPS61088 输出约 5.0V。
- 做 10 秒静止测试。
- 采样率验收按 `210-240Hz` 或中位采样间隔 `4.0-4.8ms`，不要使用过窄的 220-225Hz 判定。

### 阶段 6：动态测试

- 小幅旋转和摆臂 2 分钟。
- 模拟投篮 10 次。
- 记录数据。
- 检查无复位、无全零、无固定饱和、无削顶。
- 采样间隔不超过 10ms。

## 6. 到货后必须记录的调试结果

| 项目 | 预期 | 实测 | 结果 |
|---|---:|---:|---|
| 电池空载电压 | 3.0-4.2V | 待测 | 待定 |
| TP4057 充电电流 | 约 500mA | 待测 | 待定 |
| 电池充满电压 | 约 4.2V | 待测 | 待定 |
| TPS61088 空载输出 | 约 5.00V | 待测 | 待定 |
| ESP32 启动时 5V | ≥4.85V | 待测 | 待定 |
| 记录时电池平均电流 | ≤500mA | 待测 | 待定 |
| 启动峰值电流 | 尽量≤1A | 待测 | 待定 |
| ICM VCC | 约 3.3V | 待测 | 待定 |
| NCS | 约 3.3V | 待测 | 待定 |
| AD0 | 约 0V | 待测 | 待定 |
| I2C 地址 | 0x68 | 待测 | 待定 |
| WHO_AM_I | 0xEA | 待测 | 待定 |
| 静止测试 | 无异常 | 待测 | 待定 |
| 动态测试 | 无异常 | 待测 | 待定 |

## 7. 高风险项

- 电池过流保护点未知，TPS61088 启动峰值可能触发保护。
- TPS61088 标称 2A，但当前电池持续上限只有 500mA。
- TPS61088 可能发成 KF301 端子版，重量和厚度增加。
- ESP32 和 ICM 实际厚度未测量。
- 10 × 8cm 软袋偏大，投篮时可能晃动。
- 50mm 前臂带不能完全覆盖 80mm 宽的软袋。
- PH2.0 和 26AWG 线束的应力释放尚未实装。
- 万用表和魔术贴等辅助物料尚未确认。

## 8. 禁止事项

- 不使用 `0x69` 或 `0x0C` 作为长期地址。
- 不允许 `NCS` 或 `AD0` 悬空。
- 不切换 ESP32 的 3.3V 电源路径。
- 不把 5V 接到 ICM VCC。
- 不在充电时让负载长期开启。
- 不把 TPS61088 EN 当主断电开关。
- 不在未测量 5V 的情况下直接接 ESP32。
- 不把带保护板的电池长期并联使用。
- 不把根目录旧 `firmware/`、`tools/`、`data/` 当作当前固件；它们已迁入 `legacy/`。

## 9. 相关文档

- `SOFTWARE_BASELINE.md`
- `H2_HANDOFF.md`
- `H2_BOM.csv`
- `ORDER_RECEIPTS_2026-09-15.md`
- `ORDER_RECEIPTS_2026-09-15.csv`
- `WEARABLE_DIMENSIONS.md`

## 10. 当前结论

H2 第一版配件和电源方案已经确定，可以进入收货和焊接阶段。H2 当前仍为 `assembling_and_verification`，不能标记完成。当前最大剩余风险不在接线，而在电源峰值和电池保护板、TPS61088 启动浪涌以及机械尺寸。真实投篮前必须完成 10 秒静止、小幅动态、电源带载和接口复核。

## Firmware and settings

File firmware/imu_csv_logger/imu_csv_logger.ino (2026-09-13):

#include "ICM_20948.h"

#define AD0_VAL 1

ICM_20948_I2C myICM;

void setup() {
  Serial.begin(115200);
  delay(1000);
  Serial.println("IMU_CSV_BOOT");

  Wire.begin(8, 9);
  Wire.setClock(100000);

  bool initialized = false;
  while (!initialized) {
    for (uint8_t ad0 = 0; ad0 <= 1; ad0++) {
      myICM.begin(Wire, ad0);
      Serial.print("Trying AD0_VAL=");
      Serial.print(ad0);
      Serial.print(" status=");
      Serial.println(myICM.statusString());

      if (myICM.status == ICM_20948_Stat_Ok) {
        initialized = true;
        break;
      }

      delay(250);
    }

    if (!initialized) {
      Serial.println("IMU init failed, retrying");
      delay(1000);
    }
  }

  Serial.println("IMU_READY");
  Serial.println("timestamp_ms,ax_mg,ay_mg,az_mg,gx_dps,gy_dps,gz_dps,temp_c");
}

void loop() {
  if (myICM.dataReady()) {
    unsigned long timestamp = millis();
    myICM.getAGMT();

    if (myICM.status != ICM_20948_Stat_Ok) {
      Serial.println("ERROR");
      delay(100);
      return;
    }

    Serial.print(timestamp);
    Serial.print(',');
    Serial.print(myICM.accX(), 2);
    Serial.print(',');
    Serial.print(myICM.accY(), 2);
    Serial.print(',');
    Serial.print(myICM.accZ(), 2);
    Serial.print(',');
    Serial.print(myICM.gyrX(), 2);
    Serial.print(',');
    Serial.print(myICM.gyrY(), 2);
    Serial.print(',');
    Serial.print(myICM.gyrZ(), 2);
    Serial.print(',');
    Serial.println(myICM.temp(), 2);

    delay(20);
  }
}

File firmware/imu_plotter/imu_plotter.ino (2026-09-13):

#include "ICM_20948.h"

#define AD0_VAL 1

ICM_20948_I2C myICM;

void setup() {
  Serial.begin(115200);

  Wire.begin(8, 9);
  Wire.setClock(100000);

  bool initialized = false;
  while (!initialized) {
    myICM.begin(Wire, AD0_VAL);

    if (myICM.status == ICM_20948_Stat_Ok) {
      initialized = true;
    } else {
      delay(500);
    }
  }

  Serial.println("IMU_PLOT_READY");
}

void loop() {
  if (myICM.dataReady()) {
    myICM.getAGMT();

    Serial.print("AX:");
    Serial.print(myICM.accX(), 1);
    Serial.print(" AY:");
    Serial.print(myICM.accY(), 1);
    Serial.print(" AZ:");
    Serial.print(myICM.accZ(), 1);

    Serial.print(" GX:");
    Serial.print(myICM.gyrX(), 1);
    Serial.print(" GY:");
    Serial.print(myICM.gyrY(), 1);
    Serial.print(" GZ:");
    Serial.print(myICM.gyrZ(), 1);

    Serial.println();
    delay(20);
  }
}

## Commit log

2026-09-13 Initial hardware bring-up, wiring, firmware, and sensor debug data
    [imu_20260913_192923.csv, imu_20260913_193817.csv, imu_20260913_194905.csv]
2026-09-15 Add H2 hardware baseline, BOM, and software interface reference
    [H2_BOM.csv]
2026-09-15 Move v1 firmware tools data and plots under legacy
    [imu_20260913_192923.csv, imu_20260913_193817.csv, imu_20260913_194905.csv]
2026-09-15 Document legacy archive and current software entry point
2026-09-15 Specify TPS61088 boost and PMOS high-side power switch
    [H2_BOM.csv]
2026-09-15 Make single TPS61088 and PMOS options explicit
    [H2_BOM.csv]
2026-09-15 Select ready-made PMOS high-side switch option
    [H2_BOM.csv]
2026-09-15 Clarify TPS61088 EN behavior and wiring
    [H2_BOM.csv]
2026-09-15 Require fixed 5V TPS61088 jumper version
    [H2_BOM.csv]
2026-09-15 Record fixed 5V TPS61088 seller confirmation
    [H2_BOM.csv]
2026-09-15 Reject 5V minimum PMOS module for 3.7V battery path
    [H2_BOM.csv]
2026-09-15 Add 3A slide switch alternative for main power path
    [H2_BOM.csv]
2026-09-15 Select 3A slide switch for direct battery power path
    [H2_BOM.csv]
2026-09-15 Update ESP32 and ICM dimensions from merchant drawings
2026-09-15 Clarify minimum pouch size for current ESP32 board
2026-09-15 Record TPS61088 solder-pad and terminal dimensions
2026-09-15 Confirm direct 3A switch as primary power path
2026-09-15 Add itemized purchase order BOM and totals
    [ORDER_RECEIPTS_2026-09-15.csv]
2026-09-15 Record 0.5C battery discharge limit
    [H2_BOM.csv]
2026-09-15 Record confirmed battery discharge and charge ratings
    [H2_BOM.csv]
2026-09-15 Record boost module procurement gap and sync lesson
    [H2_BOM.csv]
2026-09-15 Apply software sync corrections P0 P1 P2
    [H2_BOM.csv]
2026-09-16 Clarify current software test power boundary
2026-09-18 Align H2 docs with received parts and assembly runbook
    [H2_BOM.csv, ORDER_RECEIPTS_2026-09-15.csv]
2026-09-18 Record battery charger pre-check and module arrival photos
2026-09-18 Record TP4057 standalone charge pass
2026-09-18 Record factory-configured 5V output test
2026-09-19 Document inline switch wiring when BAT pads are occupied
2026-09-19 Record inline switch power-path test
2026-09-19 Clarify H2 switch and P-MOS fallback
    # Conflicts:
    # README.md
    # docs/hardware/H2_BOM.csv
    # docs/hardware/H2_HANDOFF.md
2026-09-19 Sync hardware fixation requirements from action-chain tests
2026-09-19 Document battery and boost integration sequence
2026-09-19 Record battery switch and ESP32 power-cycle pass
2026-09-19 Record battery cold-start and capture completion
2026-09-19 Record battery capture software acceptance
2026-09-20 Record transparent box dry-fit enclosure
2026-09-20 Record independent dual-node power decision
2026-09-20 Add Node 2 enclosure measurement sheet
2026-09-22 Add Node 2 open-top printable enclosure model
    [node2_open_top_v1.3mf, node2_open_top_v1.stl]
2026-09-22 Update Node 2 enclosure with measured dimensions
    [node2_open_top_v1.3mf, node2_open_top_v1.stl]
2026-09-22 Fix Node 2 ICM partition clearance
    [node2_open_top_v1.3mf, node2_open_top_v1.stl]
2026-09-30 Document ESP32 replacement BLE trigger and app
